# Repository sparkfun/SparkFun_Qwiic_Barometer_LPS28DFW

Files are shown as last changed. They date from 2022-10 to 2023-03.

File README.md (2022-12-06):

SparkFun Absolute Digital Barometer - LPS28DFW (Qwiic)
======================================================

<table class="table table-striped table-bordered"?
  <tr align="center">
    <td><a href="https://www.sparkfun.com/products/21221">SparkFun Absolute Digital Barometer - LPS28DFW (Qwiic)</a></td>
    <td><a href="https://www.sparkfun.com/products/21222">SparkFun Micro Triple Axis Accelerometer Breakout - BMA400 (Qwiic)</a></td>
  </tr>
  <tr align="center">
    <td><a href="https://www.sparkfun.com/products/21221"><i>SparkFun Absolute Digital Barometer - LPS28DFW (Qwiic)</i></a></td>
    <td><a href="https://www.sparkfun.com/products/21222"><i>SparkFun Micro Absolute Digital Barometer - LPS28DFW (Qwiic)</i></a></td>
  </tr>
</table>

The SparkFun Qwiic LPS28DFW Absolute Digital Barometer offers a unique barometer breakout featuring the LPS28DFW from STMicroelectronics<sup>&copy;</sup>. The LPS28DFW is an absolute barometer with a water-resistant package making it perfect for pressure measurement applications where the sensor is exposed to or even submerged in water. The Qwiic system allows for integration into your I<sup>2</sup>C system with no soldering required. This Qwiic breakout also includes 0.1"-spaced PTH pins connected to the sensor's communication interface and interrupt pins for applications that require a traditional soldered connection.

The sensor has two full-scale measurement ranges of 260 - 1260hPa and 260 - 4060hPa with an absolute pressure accuracy of 0.5hPa. The LPS28DFW is composed of a piezoresistive pressure sensor with a metal lid and gel encasing to protect the sensing elements from water and other environmental hazards.

Repository Contents
-------------------
* **/Documents** - Datasheet
* **/Hardware** - Eagle design files (.brd, .sch)
* **/Production** - Production panel files (.brd)

Documentation
-------------
* **[Hookup Guide](https://learn.sparkfun.com/tutorials/sparkfun-absolute-digital-barometer---lps28dfw-qwiic-hookup-guide)** - Basic Hookup Guide for the SparkFun Absolute Digital Barometer - LPS28DFW (Qwiic). 
* **[LPS28DFW Arduino Library](https://github.com/sparkfun/SparkFun_LPS28DFW_Arduino_Library)** - Arduino library for the LPS28DFW based off the STMicroelectronics API.

Product Versions
----------------
* [SEN-21221](https://www.sparkfun.com/products/21208) - Standard Size Initial Release.
* [SEN-21222](https://www.sparkfun.com/products/21207) - Micro Size Initial Release.

License Information
-------------------

This product is _**open source**_! 

Please review the LICENSE.md file for license information.

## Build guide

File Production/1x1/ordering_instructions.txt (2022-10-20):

panel size, 169x117mm
PCB thickness, 1.6mm
number of layers, 2
soldermask color, Red
silkscreen color, White
oz copper, 1oz
finish, HASL lead free
stencils, top
pcs per panel, 24
min trace width, 0.2540mm / 0.0100in
min drill size, 0.3048mm / 0.0120in

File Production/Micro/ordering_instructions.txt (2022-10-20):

panel size, 79x170mm
PCB thickness, 1.6mm
number of layers, 2
soldermask color, Red
silkscreen color, White
oz copper, 1oz
finish, HASL lead free
stencils, top
pcs per panel, 64
min trace width, 0.1270mm / 0.0050in
min drill size, 0.3048mm / 0.0120in

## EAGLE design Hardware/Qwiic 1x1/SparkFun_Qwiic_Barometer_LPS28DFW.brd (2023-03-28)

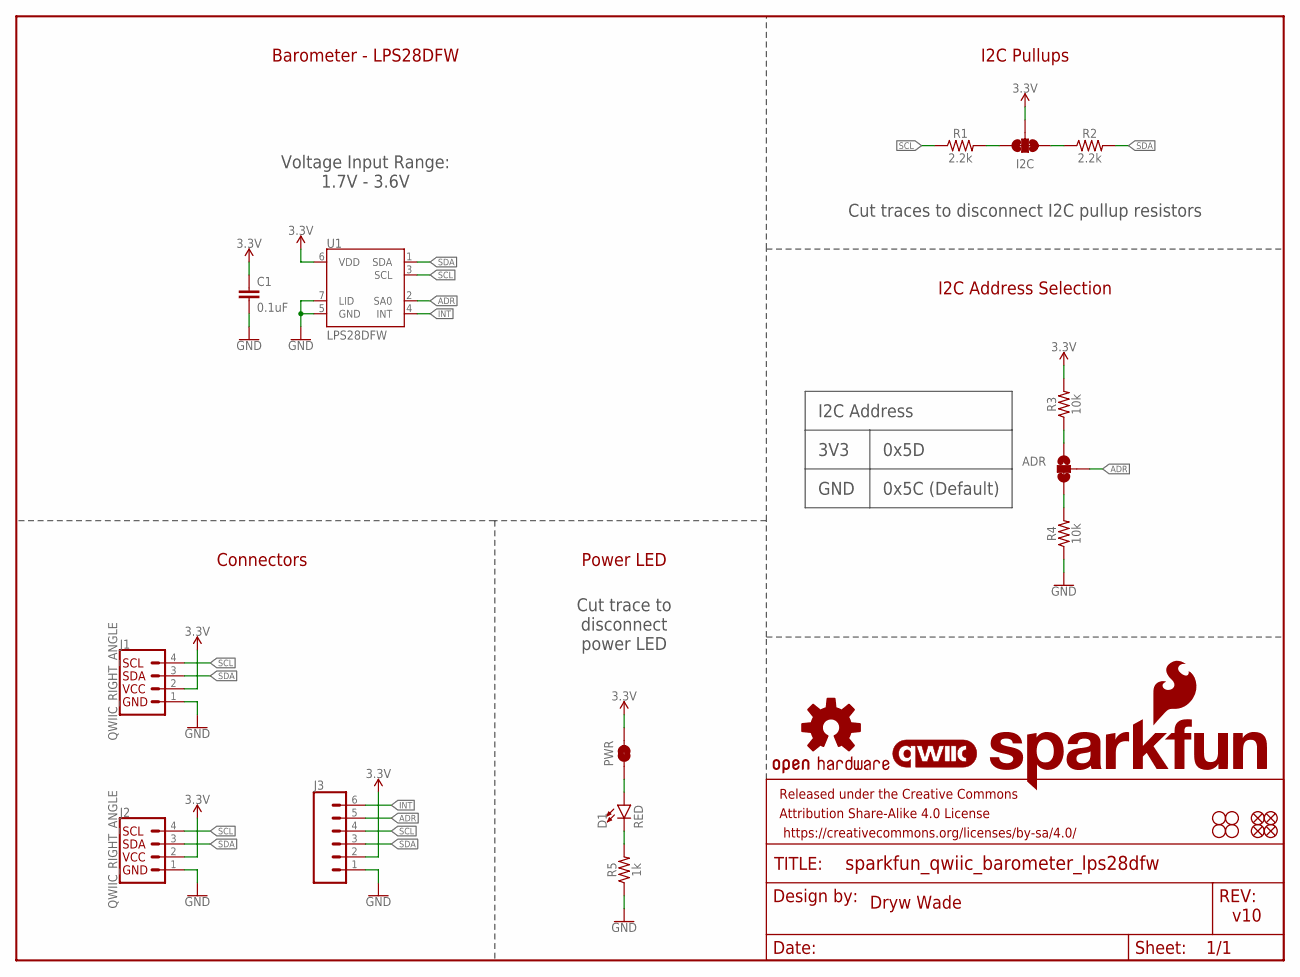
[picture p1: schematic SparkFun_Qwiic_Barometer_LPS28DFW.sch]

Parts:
ADR: JUMPER-SMT_3_1-NC_TRACE_SILK; SMT-JUMPER_3_1-NC_TRACE_SILK
C1: 0.1uF; 0603
D1: RED; LED-0603
FD1, FD2, FD3, FD4: FIDUCIAL1X2; FIDUCIAL-1X2
FRAME1: FRAME-LETTER; CREATIVE_COMMONS
H1, H2, H3, H4: STAND-OFF
I2C: JUMPER-SMT_3_2-NC_TRACE_SILK; SMT-JUMPER_3_2-NC_TRACE_SILK
J1, J2: QWIIC_RIGHT_ANGLE; JST04_1MM_RA
J3: CONN_06NO_SILK_NO_POP; 1X06_NO_SILK
LOGO1: OSHW-LOGOS; OSHW-LOGO-S
LOGO2: QWIIC_LOGO_5MM; QWIIC_5MM
LOGO3: SFE_LOGO_NAME_FLAME.1_INCH; SFE_LOGO_NAME_FLAME_.1
PWR: JUMPER-SMT_2_NC_TRACE_SILK; SMT-JUMPER_2_NC_TRACE_SILK
R1, R2: 2.2k; 0603
R3, R4: 10k; 0603
R5: 1k; 0603
U1: LPS28DFW; CCLGA-7L

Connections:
3.3V: C1.1, I2C.2, J1.2, J2.2, J3.2, PWR.2, R3.2, U1.6 (VDD)
ADR: ADR.2, J3.5, U1.2 (SA0)
GND: C1.2, J1.1, J2.1, J3.1, R4.1, R5.1, U1.5 (GND), U1.7 (LID)
INT: J3.6, U1.4 (INT)
unnamed: D1.C, R5.2
unnamed: I2C.3, R1.2
unnamed: I2C.1, R2.1
unnamed: D1.A, PWR.1
unnamed: ADR.3, R4.2
unnamed: ADR.1, R3.1
SCL: J1.4, J2.4, J3.4, R1.1, U1.3 (SCL)
SDA: J1.3, J2.3, J3.3, R2.2, U1.1 (SDA)

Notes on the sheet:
Dryw Wade
v10
Barometer - LPS28DFW
I2C Pullups
I2C Address Selection
Connectors
Power LED
Cut traces to disconnect I2C pullup resistors
I2C Address
GND
3V3
0x5D
0x5C (Default)
Cut trace to disconnect power LED
Voltage Input Range: 1.7V - 3.6V

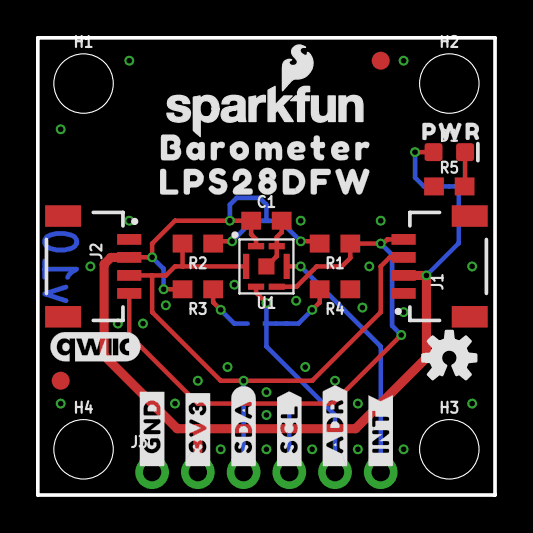
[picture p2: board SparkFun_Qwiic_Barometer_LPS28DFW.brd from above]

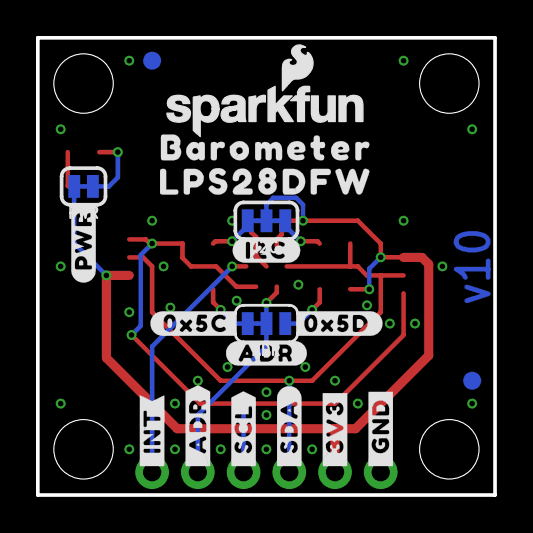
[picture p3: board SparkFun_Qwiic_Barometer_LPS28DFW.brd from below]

Board: 2 copper layers, 25.4 x 25.4 mm, 50 parts (19 on the bottom side), 12 nets.

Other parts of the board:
LOGO4: SFE_LOGO_NAME_FLAME.1_INCH; SFE_LOGO_NAME_FLAME_.1
U$1, U$2: #_GND#0
U$3, U$4: #_3V3#0
U$5, U$6: #_SDA#0
U$7, U$8: #_SCL#0
U$9: #I2C#0
U$10: #ADR#0
U$11, U$14: BAROMETER0
U$12, U$15: LPS28DFW0
U$13: #PWR#0
U$16: #0X5D#0
U$17: #0X5C#0
U$18: PWR0
U$19: ORDERING_INSTRUCTIONS
U$20, U$21: #_INT#0
U$22, U$23: #_ADR#0

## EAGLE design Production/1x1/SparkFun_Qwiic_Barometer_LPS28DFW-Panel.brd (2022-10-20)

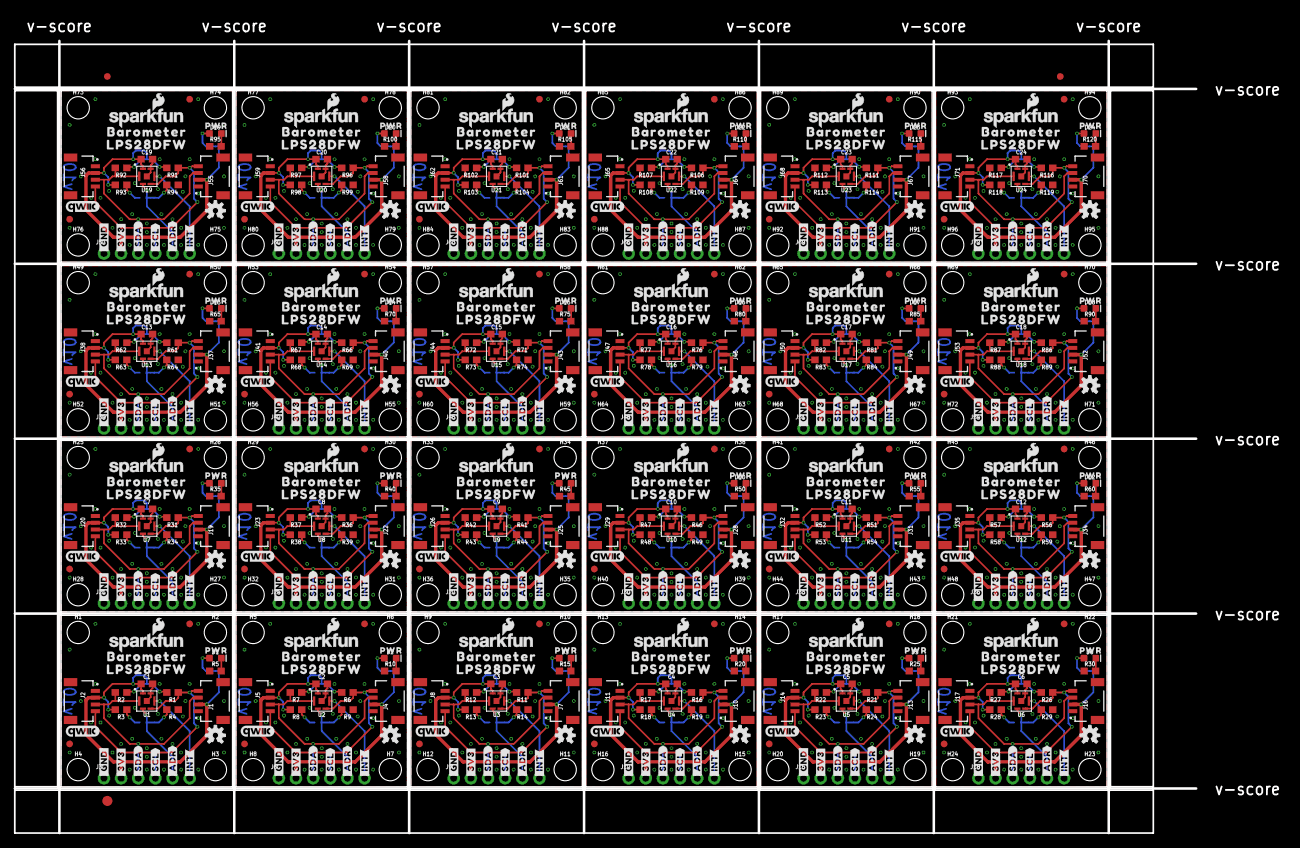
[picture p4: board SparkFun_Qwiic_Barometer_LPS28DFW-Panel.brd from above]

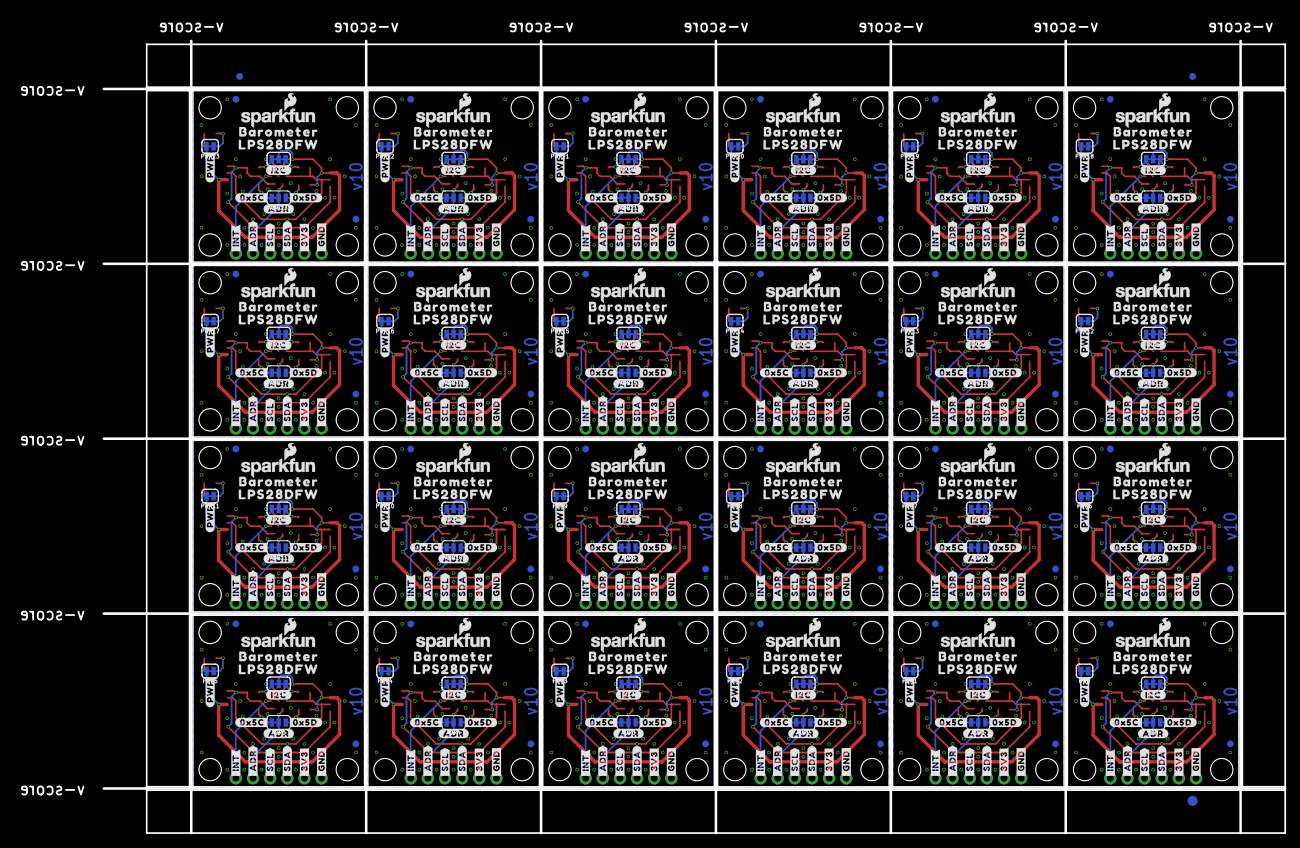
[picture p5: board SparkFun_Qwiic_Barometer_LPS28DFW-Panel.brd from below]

Board: 2 copper layers, 175.0 x 117.3 mm, 1158 parts (459 on the bottom side), 288 nets.

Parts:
ADR, ADR1, ADR2, ADR3, ADR4, ADR5, ADR6, ADR7, ADR8, ADR9, ADR10, ADR11, ADR12, ADR13, ADR14, ADR15, ADR16, ADR17, ADR18, ADR19, ADR20, ADR21, ADR22, ADR23: JUMPER-SMT_3_1-NC_TRACE_SILK; SMT-JUMPER_3_1-NC_TRACE_SILK
C1, C2, C3, C4, C5, C6, C7, C8, C9, C10, C11, C12, C13, C14, C15, C16, C17, C18, C19, C20, C21, C22, C23, C24: 0.1uF; 0603
D1, D2, D3, D4, D5, D6, D7, D8, D9, D10, D11, D12, D13, D14, D15, D16, D17, D18, D19, D20, D21, D22, D23, D24: RED; LED-0603
E$1, E$2, E$3, E$4: FIDUCIAL-1X2
E$5, E$6: FIDUCIAL-1.5X3
FD1, FD2, FD3, FD4, FD5, FD6, FD7, FD8, FD9, FD10, FD11, FD12, FD13, FD14, FD15, FD16, FD17, FD18, FD19, FD20, FD21, FD22, FD23, FD24, FD25, FD26, FD27, FD28, FD29, FD30, FD31, FD32, FD33, FD34, FD35, FD36, FD37, FD38, FD39, FD40, FD41, FD42, FD43, FD44, FD45, FD46, FD47, FD48, FD49, FD50, FD51, FD52, FD53, FD54, FD55, FD56, FD57, FD58, FD59, FD60, FD61, FD62, FD63, FD64, FD65, FD66, FD67, FD68, FD69, FD70, FD71, FD72, FD73, FD74, FD75, FD76, FD77, FD78, FD79, FD80, FD81, FD82, FD83, FD84, FD85, FD86, FD87, FD88, FD89, FD90, FD91, FD92, FD93, FD94, FD95, FD96: FIDUCIAL1X2; FIDUCIAL-1X2
H1, H2, H3, H4, H5, H6, H7, H8, H9, H10, H11, H12, H13, H14, H15, H16, H17, H18, H19, H20, H21, H22, H23, H24, H25, H26, H27, H28, H29, H30, H31, H32, H33, H34, H35, H36, H37, H38, H39, H40, H41, H42, H43, H44, H45, H46, H47, H48, H49, H50, H51, H52, H53, H54, H55, H56, H57, H58, H59, H60, H61, H62, H63, H64, H65, H66, H67, H68, H69, H70, H71, H72, H73, H74, H75, H76, H77, H78, H79, H80, H81, H82, H83, H84, H85, H86, H87, H88, H89, H90, H91, H92, H93, H94, H95, H96: STAND-OFF
I2C, I2C1, I2C2, I2C3, I2C4, I2C5, I2C6, I2C7, I2C8, I2C9, I2C10, I2C11, I2C12, I2C13, I2C14, I2C15, I2C16, I2C17, I2C18, I2C19, I2C20, I2C21, I2C22, I2C23: JUMPER-SMT_3_2-NC_TRACE_SILK; SMT-JUMPER_3_2-NC_TRACE_SILK
J1, J2, J4, J5, J7, J8, J10, J11, J13, J14, J16, J17, J19, J20, J22, J23, J25, J26, J28, J29, J31, J32, J34, J35, J37, J38, J40, J41, J43, J44, J46, J47, J49, J50, J52, J53, J55, J56, J58, J59, J61, J62, J64, J65, J67, J68, J70, J71: QWIIC_RIGHT_ANGLE; JST04_1MM_RA
J3, J6, J9, J12, J15, J18, J21, J24, J27, J30, J33, J36, J39, J42, J45, J48, J51, J54, J57, J60, J63, J66, J69, J72: 1X06_NO_SILK
LOGO1, LOGO5, LOGO9, LOGO13, LOGO17, LOGO21, LOGO25, LOGO29, LOGO33, LOGO37, LOGO41, LOGO45, LOGO49, LOGO53, LOGO57, LOGO61, LOGO65, LOGO69, LOGO73, LOGO77, LOGO81, LOGO85, LOGO89, LOGO93: OSHW-LOGOS; OSHW-LOGO-S
LOGO2, LOGO6, LOGO10, LOGO14, LOGO18, LOGO22, LOGO26, LOGO30, LOGO34, LOGO38, LOGO42, LOGO46, LOGO50, LOGO54, LOGO58, LOGO62, LOGO66, LOGO70, LOGO74, LOGO78, LOGO82, LOGO86, LOGO90, LOGO94: QWIIC_LOGO_5MM; QWIIC_5MM
LOGO3, LOGO4, LOGO7, LOGO8, LOGO11, LOGO12, LOGO15, LOGO16, LOGO19, LOGO20, LOGO23, LOGO24, LOGO27, LOGO28, LOGO31, LOGO32, LOGO35, LOGO36, LOGO39, LOGO40, LOGO43, LOGO44, LOGO47, LOGO48, LOGO51, LOGO52, LOGO55, LOGO56, LOGO59, LOGO60, LOGO63, LOGO64, LOGO67, LOGO68, LOGO71, LOGO72, LOGO75, LOGO76, LOGO79, LOGO80, LOGO83, LOGO84, LOGO87, LOGO88, LOGO91, LOGO92, LOGO95, LOGO96: SFE_LOGO_NAME_FLAME.1_INCH; SFE_LOGO_NAME_FLAME_.1
PWR, PWR1, PWR2, PWR3, PWR4, PWR5, PWR6, PWR7, PWR8, PWR9, PWR10, PWR11, PWR12, PWR13, PWR14, PWR15, PWR16, PWR17, PWR18, PWR19, PWR20, PWR21, PWR22, PWR23: JUMPER-SMT_2_NC_TRACE_SILK; SMT-JUMPER_2_NC_TRACE_SILK
R1, R2, R6, R7, R11, R12, R16, R17, R21, R22, R26, R27, R31, R32, R36, R37, R41, R42, R46, R47, R51, R52, R56, R57, R61, R62, R66, R67, R71, R72, R76, R77, R81, R82, R86, R87, R91, R92, R96, R97, R101, R102, R106, R107, R111, R112, R116, R117: 2.2k; 0603
R3, R4, R8, R9, R13, R14, R18, R19, R23, R24, R28, R29, R33, R34, R38, R39, R43, R44, R48, R49, R53, R54, R58, R59, R63, R64, R68, R69, R73, R74, R78, R79, R83, R84, R88, R89, R93, R94, R98, R99, R103, R104, R108, R109, R113, R114, R118, R119: 10k; 0603
R5, R10, R15, R20, R25, R30, R35, R40, R45, R50, R55, R60, R65, R70, R75, R80, R85, R90, R95, R100, R105, R110, R115, R120: 1k; 0603
U1, U2, U3, U4, U5, U6, U7, U8, U9, U10, U11, U12, U13, U14, U15, U16, U17, U18, U19, U20, U21, U22, U23, U24: LPS28DFW
U$1, U$2, U$19, U$24, U$45, U$46, U$67, U$68, U$89, U$90, U$111, U$112, U$133, U$134, U$155, U$156, U$177, U$178, U$199, U$200, U$221, U$222, U$243, U$244, U$265, U$266, U$287, U$288, U$309, U$310, U$331, U$332, U$353, U$354, U$375, U$376, U$397, U$398, U$419, U$420, U$441, U$442, U$463, U$464, U$485, U$486, U$507, U$508: #_GND#0
U$3, U$4, U$25, U$26, U$47, U$48, U$69, U$70, U$91, U$92, U$113, U$114, U$135, U$136, U$157, U$158, U$179, U$180, U$201, U$202, U$223, U$224, U$245, U$246, U$267, U$268, U$289, U$290, U$311, U$312, U$333, U$334, U$355, U$356, U$377, U$378, U$399, U$400, U$421, U$422, U$443, U$444, U$465, U$466, U$487, U$488, U$509, U$510: #_3V3#0
U$5, U$6, U$27, U$28, U$49, U$50, U$71, U$72, U$93, U$94, U$115, U$116, U$137, U$138, U$159, U$160, U$181, U$182, U$203, U$204, U$225, U$226, U$247, U$248, U$269, U$270, U$291, U$292, U$313, U$314, U$335, U$336, U$357, U$358, U$379, U$380, U$401, U$402, U$423, U$424, U$445, U$446, U$467, U$468, U$489, U$490, U$511, U$512: #_SDA#0
U$7, U$8, U$29, U$30, U$51, U$52, U$73, U$74, U$95, U$96, U$117, U$118, U$139, U$140, U$161, U$162, U$183, U$184, U$205, U$206, U$227, U$228, U$249, U$250, U$271, U$272, U$293, U$294, U$315, U$316, U$337, U$338, U$359, U$360, U$381, U$382, U$403, U$404, U$425, U$426, U$447, U$448, U$469, U$470, U$491, U$492, U$513, U$514: #_SCL#0
U$9, U$31, U$53, U$75, U$97, U$119, U$141, U$163, U$185, U$207, U$229, U$251, U$273, U$295, U$317, U$339, U$361, U$383, U$405, U$427, U$449, U$471, U$493, U$515: #I2C#0
U$10, U$32, U$54, U$76, U$98, U$120, U$142, U$164, U$186, U$208, U$230, U$252, U$274, U$296, U$318, U$340, U$362, U$384, U$406, U$428, U$450, U$472, U$494, U$516: #ADR#0
U$11, U$14, U$33, U$36, U$55, U$58, U$77, U$80, U$99, U$102, U$121, U$124, U$143, U$146, U$165, U$168, U$187, U$190, U$209, U$212, U$231, U$234, U$253, U$256, U$275, U$278, U$297, U$300, U$319, U$322, U$341, U$344, U$363, U$366, U$385, U$388, U$407, U$410, U$429, U$432, U$451, U$454, U$473, U$476, U$495, U$498, U$517, U$520: BAROMETER0
U$12, U$15, U$34, U$37, U$56, U$59, U$78, U$81, U$100, U$103, U$122, U$125, U$144, U$147, U$166, U$169, U$188, U$191, U$210, U$213, U$232, U$235, U$254, U$257, U$276, U$279, U$298, U$301, U$320, U$323, U$342, U$345, U$364, U$367, U$386, U$389, U$408, U$411, U$430, U$433, U$452, U$455, U$474, U$477, U$496, U$499, U$518, U$521: LPS28DFW0
U$13, U$35, U$57, U$79, U$101, U$123, U$145, U$167, U$189, U$211, U$233, U$255, U$277, U$299, U$321, U$343, U$365, U$387, U$409, U$431, U$453, U$475, U$497, U$519: #PWR#0
U$16, U$38, U$60, U$82, U$104, U$126, U$148, U$170, U$192, U$214, U$236, U$258, U$280, U$302, U$324, U$346, U$368, U$390, U$412, U$434, U$456, U$478, U$500, U$522: #0X5D#0
U$17, U$39, U$61, U$83, U$105, U$127, U$149, U$171, U$193, U$215, U$237, U$259, U$281, U$303, U$325, U$347, U$369, U$391, U$413, U$435, U$457, U$479, U$501, U$523: #0X5C#0
U$18, U$44, U$66, U$88, U$110, U$132, U$154, U$176, U$198, U$220, U$242, U$264, U$286, U$308, U$330, U$352, U$374, U$396, U$418, U$440, U$462, U$484, U$506, U$528: PWR0
U$20, U$21, U$40, U$41, U$62, U$63, U$84, U$85, U$106, U$107, U$128, U$129, U$150, U$151, U$172, U$173, U$194, U$195, U$216, U$217, U$238, U$239, U$260, U$261, U$282, U$283, U$304, U$305, U$326, U$327, U$348, U$349, U$370, U$371, U$392, U$393, U$414, U$415, U$436, U$437, U$458, U$459, U$480, U$481, U$502, U$503, U$524, U$525: #_INT#0
U$22, U$23, U$42, U$43, U$64, U$65, U$86, U$87, U$108, U$109, U$130, U$131, U$152, U$153, U$174, U$175, U$196, U$197, U$218, U$219, U$240, U$241, U$262, U$263, U$284, U$285, U$306, U$307, U$328, U$329, U$350, U$351, U$372, U$373, U$394, U$395, U$416, U$417, U$438, U$439, U$460, U$461, U$482, U$483, U$504, U$505, U$526, U$527: #_ADR#0

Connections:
3.3V: C1.1, I2C.2, J1.2, J2.2, J3.2, PWR.2, R3.2, U1.6
3.3V1: C2.1, I2C1.2, J4.2, J5.2, J6.2, PWR1.2, R8.2, U2.6
3.3V2: C3.1, I2C2.2, J7.2, J8.2, J9.2, PWR2.2, R13.2, U3.6
3.3V3: C4.1, I2C3.2, J10.2, J11.2, J12.2, PWR3.2, R18.2, U4.6
3.3V4: C5.1, I2C4.2, J13.2, J14.2, J15.2, PWR4.2, R23.2, U5.6
3.3V5: C6.1, I2C5.2, J16.2, J17.2, J18.2, PWR5.2, R28.2, U6.6
3.3V6: C7.1, I2C6.2, J19.2, J20.2, J21.2, PWR6.2, R33.2, U7.6
3.3V7: C8.1, I2C7.2, J22.2, J23.2, J24.2, PWR7.2, R38.2, U8.6
3.3V8: C9.1, I2C8.2, J25.2, J26.2, J27.2, PWR8.2, R43.2, U9.6
3.3V9: C10.1, I2C9.2, J28.2, J29.2, J30.2, PWR9.2, R48.2, U10.6
3.3V10: C11.1, I2C10.2, J31.2, J32.2, J33.2, PWR10.2, R53.2, U11.6
3.3V11: C12.1, I2C11.2, J34.2, J35.2, J36.2, PWR11.2, R58.2, U12.6
3.3V12: C13.1, I2C12.2, J37.2, J38.2, J39.2, PWR12.2, R63.2, U13.6
3.3V13: C14.1, I2C13.2, J40.2, J41.2, J42.2, PWR13.2, R68.2, U14.6
3.3V14: C15.1, I2C14.2, J43.2, J44.2, J45.2, PWR14.2, R73.2, U15.6
3.3V15: C16.1, I2C15.2, J46.2, J47.2, J48.2, PWR15.2, R78.2, U16.6
3.3V16: C17.1, I2C16.2, J49.2, J50.2, J51.2, PWR16.2, R83.2, U17.6
3.3V17: C18.1, I2C17.2, J52.2, J53.2, J54.2, PWR17.2, R88.2, U18.6
3.3V18: C19.1, I2C18.2, J55.2, J56.2, J57.2, PWR18.2, R93.2, U19.6
3.3V19: C20.1, I2C19.2, J58.2, J59.2, J60.2, PWR19.2, R98.2, U20.6
3.3V20: C21.1, I2C20.2, J61.2, J62.2, J63.2, PWR20.2, R103.2, U21.6
3.3V21: C22.1, I2C21.2, J64.2, J65.2, J66.2, PWR21.2, R108.2, U22.6
3.3V22: C23.1, I2C22.2, J67.2, J68.2, J69.2, PWR22.2, R113.2, U23.6
3.3V23: C24.1, I2C23.2, J70.2, J71.2, J72.2, PWR23.2, R118.2, U24.6
ADR: ADR.2, J3.5, U1.2
ADR1: ADR1.2, J6.5, U2.2
ADR2: ADR2.2, J9.5, U3.2
ADR3: ADR3.2, J12.5, U4.2
ADR4: ADR4.2, J15.5, U5.2
ADR5: ADR5.2, J18.5, U6.2
ADR6: ADR6.2, J21.5, U7.2
ADR7: ADR7.2, J24.5, U8.2
ADR8: ADR8.2, J27.5, U9.2
ADR9: ADR9.2, J30.5, U10.2
ADR10: ADR10.2, J33.5, U11.2
ADR11: ADR11.2, J36.5, U12.2
ADR12: ADR12.2, J39.5, U13.2
ADR13: ADR13.2, J42.5, U14.2
ADR14: ADR14.2, J45.5, U15.2
ADR15: ADR15.2, J48.5, U16.2
ADR16: ADR16.2, J51.5, U17.2
ADR17: ADR17.2, J54.5, U18.2
ADR18: ADR18.2, J57.5, U19.2
ADR19: ADR19.2, J60.5, U20.2
ADR20: ADR20.2, J63.5, U21.2
ADR21: ADR21.2, J66.5, U22.2
ADR22: ADR22.2, J69.5, U23.2
ADR23: ADR23.2, J72.5, U24.2
GND: C1.2, J1.1, J2.1, J3.1, R4.1, R5.1, U1.5, U1.7
GND1: C2.2, J4.1, J5.1, J6.1, R9.1, R10.1, U2.5, U2.7
GND2: C3.2, J7.1, J8.1, J9.1, R14.1, R15.1, U3.5, U3.7
GND3: C4.2, J10.1, J11.1, J12.1, R19.1, R20.1, U4.5, U4.7
GND4: C5.2, J13.1, J14.1, J15.1, R24.1, R25.1, U5.5, U5.7
GND5: C6.2, J16.1, J17.1, J18.1, R29.1, R30.1, U6.5, U6.7
GND6: C7.2, J19.1, J20.1, J21.1, R34.1, R35.1, U7.5, U7.7
GND7: C8.2, J22.1, J23.1, J24.1, R39.1, R40.1, U8.5, U8.7
GND8: C9.2, J25.1, J26.1, J27.1, R44.1, R45.1, U9.5, U9.7
GND9: C10.2, J28.1, J29.1, J30.1, R49.1, R50.1, U10.5, U10.7
GND10: C11.2, J31.1, J32.1, J33.1, R54.1, R55.1, U11.5, U11.7
GND11: C12.2, J34.1, J35.1, J36.1, R59.1, R60.1, U12.5, U12.7
GND12: C13.2, J37.1, J38.1, J39.1, R64.1, R65.1, U13.5, U13.7
GND13: C14.2, J40.1, J41.1, J42.1, R69.1, R70.1, U14.5, U14.7
GND14: C15.2, J43.1, J44.1, J45.1, R74.1, R75.1, U15.5, U15.7
GND15: C16.2, J46.1, J47.1, J48.1, R79.1, R80.1, U16.5, U16.7
GND16: C17.2, J49.1, J50.1, J51.1, R84.1, R85.1, U17.5, U17.7
GND17: C18.2, J52.1, J53.1, J54.1, R89.1, R90.1, U18.5, U18.7
GND18: C19.2, J55.1, J56.1, J57.1, R94.1, R95.1, U19.5, U19.7
GND19: C20.2, J58.1, J59.1, J60.1, R99.1, R100.1, U20.5, U20.7
GND20: C21.2, J61.1, J62.1, J63.1, R104.1, R105.1, U21.5, U21.7
GND21: C22.2, J64.1, J65.1, J66.1, R109.1, R110.1, U22.5, U22.7
GND22: C23.2, J67.1, J68.1, J69.1, R114.1, R115.1, U23.5, U23.7
GND23: C24.2, J70.1, J71.1, J72.1, R119.1, R120.1, U24.5, U24.7
INT: J3.6, U1.4
INT1: J6.6, U2.4
INT2: J9.6, U3.4
INT3: J12.6, U4.4
INT4: J15.6, U5.4
INT5: J18.6, U6.4
INT6: J21.6, U7.4
INT7: J24.6, U8.4
INT8: J27.6, U9.4
INT9: J30.6, U10.4
INT10: J33.6, U11.4
INT11: J36.6, U12.4
INT12: J39.6, U13.4
INT13: J42.6, U14.4
INT14: J45.6, U15.4
INT15: J48.6, U16.4
INT16: J51.6, U17.4
INT17: J54.6, U18.4
INT18: J57.6, U19.4
INT19: J60.6, U20.4
INT20: J63.6, U21.4
INT21: J66.6, U22.4
INT22: J69.6, U23.4
INT23: J72.6, U24.4
unnamed: D1.C, R5.2
unnamed: I2C.3, R1.2
unnamed: I2C.1, R2.1
unnamed: D1.A, PWR.1
unnamed: ADR.3, R4.2
unnamed: ADR.1, R3.1
unnamed: I2C1.3, R6.2
unnamed: I2C1.1, R7.1
unnamed: ADR1.3, R9.2
unnamed: ADR1.1, R8.1
unnamed: D2.C, R10.2
unnamed: D2.A, PWR1.1
unnamed: I2C2.3, R11.2
unnamed: I2C2.1, R12.1
unnamed: ADR2.3, R14.2
unnamed: ADR2.1, R13.1
unnamed: D3.C, R15.2
unnamed: D3.A, PWR2.1
unnamed: I2C3.3, R16.2
unnamed: I2C3.1, R17.1
unnamed: ADR3.3, R19.2
unnamed: ADR3.1, R18.1
unnamed: D4.C, R20.2
unnamed: D4.A, PWR3.1
unnamed: I2C4.3, R21.2
unnamed: I2C4.1, R22.1
unnamed: ADR4.3, R24.2
unnamed: ADR4.1, R23.1
unnamed: D5.C, R25.2
unnamed: D5.A, PWR4.1
unnamed: I2C5.3, R26.2
unnamed: I2C5.1, R27.1
unnamed: ADR5.3, R29.2
unnamed: ADR5.1, R28.1
unnamed: D6.C, R30.2
unnamed: D6.A, PWR5.1
unnamed: I2C6.3, R31.2
unnamed: I2C6.1, R32.1
unnamed: ADR6.3, R34.2
unnamed: ADR6.1, R33.1
unnamed: D7.C, R35.2
unnamed: D7.A, PWR6.1
unnamed: I2C7.3, R36.2
unnamed: I2C7.1, R37.1
unnamed: ADR7.3, R39.2
unnamed: ADR7.1, R38.1
unnamed: D8.C, R40.2
unnamed: D8.A, PWR7.1
unnamed: I2C8.3, R41.2
unnamed: I2C8.1, R42.1
unnamed: ADR8.3, R44.2
unnamed: ADR8.1, R43.1
unnamed: D9.C, R45.2
unnamed: D9.A, PWR8.1
unnamed: I2C9.3, R46.2
unnamed: I2C9.1, R47.1
unnamed: ADR9.3, R49.2
unnamed: ADR9.1, R48.1
unnamed: D10.C, R50.2
unnamed: D10.A, PWR9.1
unnamed: I2C10.3, R51.2
unnamed: I2C10.1, R52.1
unnamed: ADR10.3, R54.2
unnamed: ADR10.1, R53.1
unnamed: D11.C, R55.2
unnamed: D11.A, PWR10.1
unnamed: I2C11.3, R56.2
unnamed: I2C11.1, R57.1
unnamed: ADR11.3, R59.2
unnamed: ADR11.1, R58.1
unnamed: D12.C, R60.2
unnamed: D12.A, PWR11.1
unnamed: I2C12.3, R61.2
unnamed: I2C12.1, R62.1
unnamed: ADR12.3, R64.2
unnamed: ADR12.1, R63.1
unnamed: D13.C, R65.2
unnamed: D13.A, PWR12.1
unnamed: I2C13.3, R66.2
unnamed: I2C13.1, R67.1
unnamed: ADR13.3, R69.2
unnamed: ADR13.1, R68.1
unnamed: D14.C, R70.2
unnamed: D14.A, PWR13.1
unnamed: I2C14.3, R71.2
unnamed: I2C14.1, R72.1
unnamed: ADR14.3, R74.2
unnamed: ADR14.1, R73.1
unnamed: D15.C, R75.2
unnamed: D15.A, PWR14.1
unnamed: I2C15.3, R76.2
unnamed: I2C15.1, R77.1
unnamed: ADR15.3, R79.2
unnamed: ADR15.1, R78.1
unnamed: D16.C, R80.2
unnamed: D16.A, PWR15.1
unnamed: I2C16.3, R81.2
unnamed: I2C16.1, R82.1
unnamed: ADR16.3, R84.2
unnamed: ADR16.1, R83.1
unnamed: D17.C, R85.2
unnamed: D17.A, PWR16.1
unnamed: I2C17.3, R86.2
unnamed: I2C17.1, R87.1
unnamed: ADR17.3, R89.2
unnamed: ADR17.1, R88.1
unnamed: D18.C, R90.2
unnamed: D18.A, PWR17.1
unnamed: I2C18.3, R91.2
unnamed: I2C18.1, R92.1
unnamed: ADR18.3, R94.2
unnamed: ADR18.1, R93.1
unnamed: D19.C, R95.2
unnamed: D19.A, PWR18.1
unnamed: I2C19.3, R96.2
unnamed: I2C19.1, R97.1
unnamed: ADR19.3, R99.2
unnamed: ADR19.1, R98.1
unnamed: D20.C, R100.2
unnamed: D20.A, PWR19.1
unnamed: I2C20.3, R101.2
unnamed: I2C20.1, R102.1
unnamed: ADR20.3, R104.2
unnamed: ADR20.1, R103.1
unnamed: D21.C, R105.2
unnamed: D21.A, PWR20.1
unnamed: I2C21.3, R106.2
unnamed: I2C21.1, R107.1
unnamed: ADR21.3, R109.2
unnamed: ADR21.1, R108.1
unnamed: D22.C, R110.2
unnamed: D22.A, PWR21.1
unnamed: I2C22.3, R111.2
unnamed: I2C22.1, R112.1
unnamed: ADR22.3, R114.2
unnamed: ADR22.1, R113.1
unnamed: D23.C, R115.2
unnamed: D23.A, PWR22.1
unnamed: I2C23.3, R116.2
unnamed: I2C23.1, R117.1
unnamed: ADR23.3, R119.2
unnamed: ADR23.1, R118.1
unnamed: D24.C, R120.2
unnamed: D24.A, PWR23.1
SCL: J1.4, J2.4, J3.4, R1.1, U1.3
SCL1: J4.4, J5.4, J6.4, R6.1, U2.3
SCL2: J7.4, J8.4, J9.4, R11.1, U3.3
SCL3: J10.4, J11.4, J12.4, R16.1, U4.3
SCL4: J13.4, J14.4, J15.4, R21.1, U5.3
SCL5: J16.4, J17.4, J18.4, R26.1, U6.3
SCL6: J19.4, J20.4, J21.4, R31.1, U7.3
SCL7: J22.4, J23.4, J24.4, R36.1, U8.3
SCL8: J25.4, J26.4, J27.4, R41.1, U9.3
SCL9: J28.4, J29.4, J30.4, R46.1, U10.3
SCL10: J31.4, J32.4, J33.4, R51.1, U11.3
SCL11: J34.4, J35.4, J36.4, R56.1, U12.3
SCL12: J37.4, J38.4, J39.4, R61.1, U13.3
SCL13: J40.4, J41.4, J42.4, R66.1, U14.3
SCL14: J43.4, J44.4, J45.4, R71.1, U15.3
SCL15: J46.4, J47.4, J48.4, R76.1, U16.3
SCL16: J49.4, J50.4, J51.4, R81.1, U17.3
SCL17: J52.4, J53.4, J54.4, R86.1, U18.3
SCL18: J55.4, J56.4, J57.4, R91.1, U19.3
SCL19: J58.4, J59.4, J60.4, R96.1, U20.3
SCL20: J61.4, J62.4, J63.4, R101.1, U21.3
SCL21: J64.4, J65.4, J66.4, R106.1, U22.3
SCL22: J67.4, J68.4, J69.4, R111.1, U23.3
SCL23: J70.4, J71.4, J72.4, R116.1, U24.3
SDA: J1.3, J2.3, J3.3, R2.2, U1.1
SDA1: J4.3, J5.3, J6.3, R7.2, U2.1
SDA2: J7.3, J8.3, J9.3, R12.2, U3.1
SDA3: J10.3, J11.3, J12.3, R17.2, U4.1
SDA4: J13.3, J14.3, J15.3, R22.2, U5.1
SDA5: J16.3, J17.3, J18.3, R27.2, U6.1
SDA6: J19.3, J20.3, J21.3, R32.2, U7.1
SDA7: J22.3, J23.3, J24.3, R37.2, U8.1
SDA8: J25.3, J26.3, J27.3, R42.2, U9.1
SDA9: J28.3, J29.3, J30.3, R47.2, U10.1
SDA10: J31.3, J32.3, J33.3, R52.2, U11.1
SDA11: J34.3, J35.3, J36.3, R57.2, U12.1
SDA12: J37.3, J38.3, J39.3, R62.2, U13.1
SDA13: J40.3, J41.3, J42.3, R67.2, U14.1
SDA14: J43.3, J44.3, J45.3, R72.2, U15.1
SDA15: J46.3, J47.3, J48.3, R77.2, U16.1
SDA16: J49.3, J50.3, J51.3, R82.2, U17.1
SDA17: J52.3, J53.3, J54.3, R87.2, U18.1
SDA18: J55.3, J56.3, J57.3, R92.2, U19.1
SDA19: J58.3, J59.3, J60.3, R97.2, U20.1
SDA20: J61.3, J62.3, J63.3, R102.2, U21.1
SDA21: J64.3, J65.3, J66.3, R107.2, U22.1
SDA22: J67.3, J68.3, J69.3, R112.2, U23.1
SDA23: J70.3, J71.3, J72.3, R117.2, U24.1

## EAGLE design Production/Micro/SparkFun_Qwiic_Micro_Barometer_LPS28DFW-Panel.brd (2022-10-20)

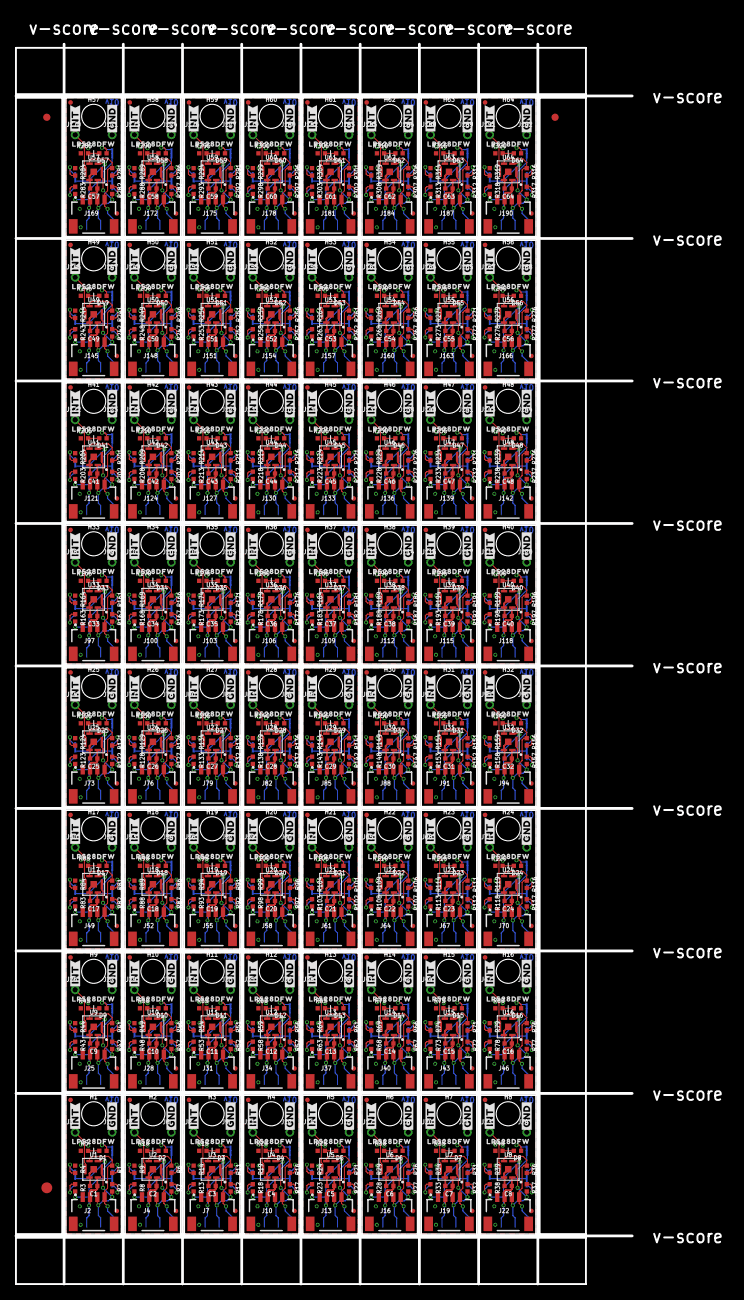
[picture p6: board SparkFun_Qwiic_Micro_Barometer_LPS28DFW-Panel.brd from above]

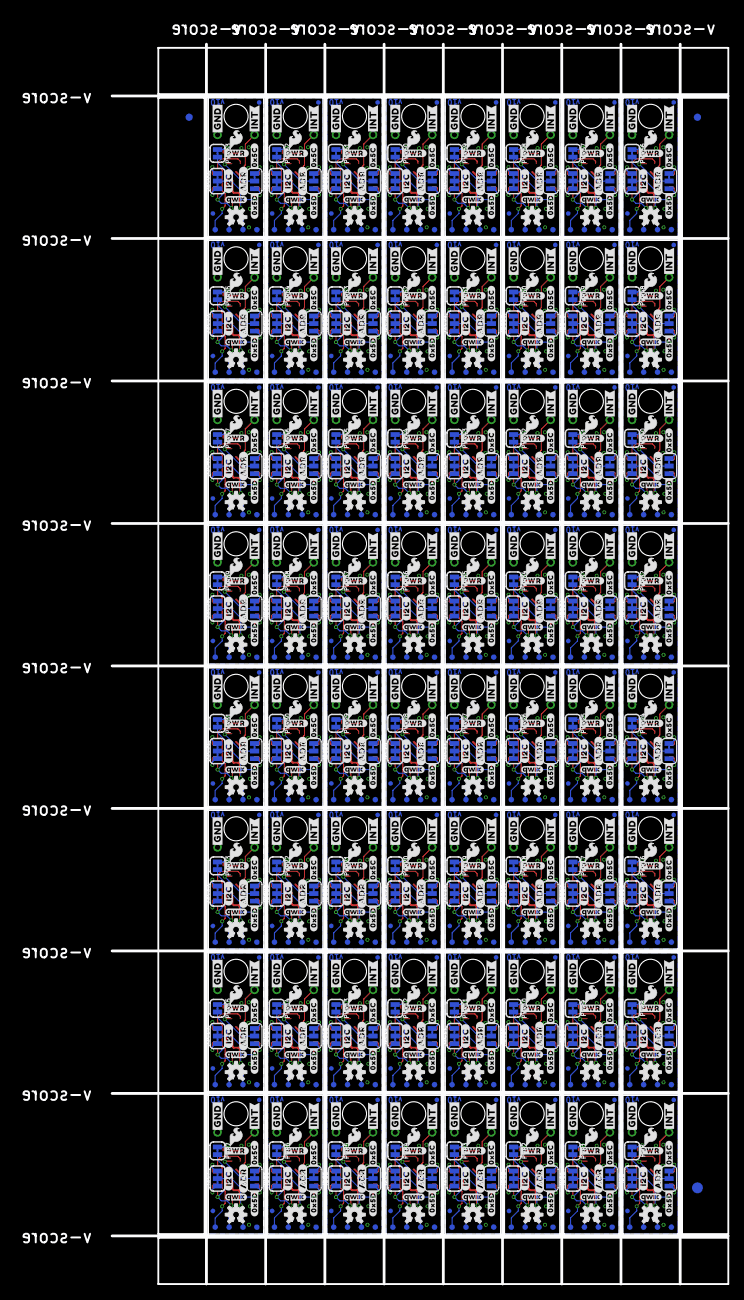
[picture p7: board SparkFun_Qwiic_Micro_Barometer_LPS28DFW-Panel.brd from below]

Board: 2 copper layers, 84.6 x 170.2 mm, 2438 parts (1219 on the bottom side), 768 nets.

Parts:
ADR, ADR1, ADR2, ADR3, ADR4, ADR5, ADR6, ADR7, ADR8, ADR9, ADR10, ADR11, ADR12, ADR13, ADR14, ADR15, ADR16, ADR17, ADR18, ADR19, ADR20, ADR21, ADR22, ADR23, ADR24, ADR25, ADR26, ADR27, ADR28, ADR29, ADR30, ADR31, ADR32, ADR33, ADR34, ADR35, ADR36, ADR37, ADR38, ADR39, ADR40, ADR41, ADR42, ADR43, ADR44, ADR45, ADR46, ADR47, ADR48, ADR49, ADR50, ADR51, ADR52, ADR53, ADR54, ADR55, ADR56, ADR57, ADR58, ADR59, ADR60, ADR61, ADR62, ADR63: JUMPER-SMT_3_1-NC_TRACE_SILK; SMT-JUMPER_3_1-NC_TRACE_SILK
C1, C2, C3, C4, C5, C6, C7, C8, C9, C10, C11, C12, C13, C14, C15, C16, C17, C18, C19, C20, C21, C22, C23, C24, C25, C26, C27, C28, C29, C30, C31, C32, C33, C34, C35, C36, C37, C38, C39, C40, C41, C42, C43, C44, C45, C46, C47, C48, C49, C50, C51, C52, C53, C54, C55, C56, C57, C58, C59, C60, C61, C62, C63, C64: 0.1uF; 0402-TIGHT
D1, D2, D3, D4, D5, D6, D7, D8, D9, D10, D11, D12, D13, D14, D15, D16, D17, D18, D19, D20, D21, D22, D23, D24, D25, D26, D27, D28, D29, D30, D31, D32, D33, D34, D35, D36, D37, D38, D39, D40, D41, D42, D43, D44, D45, D46, D47, D48, D49, D50, D51, D52, D53, D54, D55, D56, D57, D58, D59, D60, D61, D62, D63, D64: RED; LED-0402
E$1, E$2, E$3, E$4: FIDUCIAL-1X2
E$5, E$6: FIDUCIAL-1.5X3
FD1, FD2, FD3, FD4, FD5, FD6, FD7, FD8, FD9, FD10, FD11, FD12, FD13, FD14, FD15, FD16, FD17, FD18, FD19, FD20, FD21, FD22, FD23, FD24, FD25, FD26, FD27, FD28, FD29, FD30, FD31, FD32, FD33, FD34, FD35, FD36, FD37, FD38, FD39, FD40, FD41, FD42, FD43, FD44, FD45, FD46, FD47, FD48, FD49, FD50, FD51, FD52, FD53, FD54, FD55, FD56, FD57, FD58, FD59, FD60, FD61, FD62, FD63, FD64, FD65, FD66, FD67, FD68, FD69, FD70, FD71, FD72, FD73, FD74, FD75, FD76, FD77, FD78, FD79, FD80, FD81, FD82, FD83, FD84, FD85, FD86, FD87, FD88, FD89, FD90, FD91, FD92, FD93, FD94, FD95, FD96, FD97, FD98, FD99, FD100, FD101, FD102, FD103, FD104, FD105, FD106, FD107, FD108, FD109, FD110, FD111, FD112, FD113, FD114, FD115, FD116, FD117, FD118, FD119, FD120, FD121, FD122, FD123, FD124, FD125, FD126, FD127, FD128, FD129, FD130, FD131, FD132, FD133, FD134, FD135, FD136, FD137, FD138, FD139, FD140, FD141, FD142, FD143, FD144, FD145, FD146, FD147, FD148, FD149, FD150, FD151, FD152, FD153, FD154, FD155, FD156, FD157, FD158, FD159, FD160, FD161, FD162, FD163, FD164, FD165, FD166, FD167, FD168, FD169, FD170, FD171, FD172, FD173, FD174, FD175, FD176, FD177, FD178, FD179, FD180, FD181, FD182, FD183, FD184, FD185, FD186, FD187, FD188, FD189, FD190, FD191, FD192, FD193, FD194, FD195, FD196, FD197, FD198, FD199, FD200, FD201, FD202, FD203, FD204, FD205, FD206, FD207, FD208, FD209, FD210, FD211, FD212, FD213, FD214, FD215, FD216, FD217, FD218, FD219, FD220, FD221, FD222, FD223, FD224, FD225, FD226, FD227, FD228, FD229, FD230, FD231, FD232, FD233, FD234, FD235, FD236, FD237, FD238, FD239, FD240, FD241, FD242, FD243, FD244, FD245, FD246, FD247, FD248, FD249, FD250, FD251, FD252, FD253, FD254, FD255, FD256: FIDUCIALUFIDUCIAL; FIDUCIAL-MICRO
FRAME1, FRAME2, FRAME3, FRAME4, FRAME5, FRAME6, FRAME7, FRAME8, FRAME9, FRAME10, FRAME11, FRAME12, FRAME13, FRAME14, FRAME15, FRAME16, FRAME17, FRAME18, FRAME19, FRAME20, FRAME21, FRAME22, FRAME23, FRAME24, FRAME25, FRAME26, FRAME27, FRAME28, FRAME29, FRAME30, FRAME31, FRAME32, FRAME33, FRAME34, FRAME35, FRAME36, FRAME37, FRAME38, FRAME39, FRAME40, FRAME41, FRAME42, FRAME43, FRAME44, FRAME45, FRAME46, FRAME47, FRAME48, FRAME49, FRAME50, FRAME51, FRAME52, FRAME53, FRAME54, FRAME55, FRAME56, FRAME57, FRAME58, FRAME59, FRAME60, FRAME61, FRAME62, FRAME63, FRAME64: FRAME-LETTER; CREATIVE_COMMONS
H1, H2, H3, H4, H5, H6, H7, H8, H9, H10, H11, H12, H13, H14, H15, H16, H17, H18, H19, H20, H21, H22, H23, H24, H25, H26, H27, H28, H29, H30, H31, H32, H33, H34, H35, H36, H37, H38, H39, H40, H41, H42, H43, H44, H45, H46, H47, H48, H49, H50, H51, H52, H53, H54, H55, H56, H57, H58, H59, H60, H61, H62, H63, H64: STAND-OFF
I2C, I2C1, I2C2, I2C3, I2C4, I2C5, I2C6, I2C7, I2C8, I2C9, I2C10, I2C11, I2C12, I2C13, I2C14, I2C15, I2C16, I2C17, I2C18, I2C19, I2C20, I2C21, I2C22, I2C23, I2C24, I2C25, I2C26, I2C27, I2C28, I2C29, I2C30, I2C31, I2C32, I2C33, I2C34, I2C35, I2C36, I2C37, I2C38, I2C39, I2C40, I2C41, I2C42, I2C43, I2C44, I2C45, I2C46, I2C47, I2C48, I2C49, I2C50, I2C51, I2C52, I2C53, I2C54, I2C55, I2C56, I2C57, I2C58, I2C59, I2C60, I2C61, I2C62, I2C63: JUMPER-SMT_3_2-NC_TRACE_SILK; SMT-JUMPER_3_2-NC_TRACE_SILK
J1, J3, J5, J6, J8, J9, J11, J12, J14, J15, J17, J18, J20, J21, J23, J24, J26, J27, J29, J30, J32, J33, J35, J36, J38, J39, J41, J42, J44, J45, J47, J48, J50, J51, J53, J54, J56, J57, J59, J60, J62, J63, J65, J66, J68, J69, J71, J72, J74, J75, J77, J78, J80, J81, J83, J84, J86, J87, J89, J90, J92, J93, J95, J96, J98, J99, J101, J102, J104, J105, J107, J108, J110, J111, J113, J114, J116, J117, J119, J120, J122, J123, J125, J126, J128, J129, J131, J132, J134, J135, J137, J138, J140, J141, J143, J144, J146, J147, J149, J150, J152, J153, J155, J156, J158, J159, J161, J162, J164, J165, J167, J168, J170, J171, J173, J174, J176, J177, J179, J180, J182, J183, J185, J186, J188, J189, J191, J192: 1X01_1MM_NO_SILK
J2, J4, J7, J10, J13, J16, J19, J22, J25, J28, J31, J34, J37, J40, J43, J46, J49, J52, J55, J58, J61, J64, J67, J70, J73, J76, J79, J82, J85, J88, J91, J94, J97, J100, J103, J106, J109, J112, J115, J118, J121, J124, J127, J130, J133, J136, J139, J142, J145, J148, J151, J154, J157, J160, J163, J166, J169, J172, J175, J178, J181, J184, J187, J190: QWIIC_RIGHT_ANGLE; JST04_1MM_RA
LOGO1, LOGO4, LOGO7, LOGO10, LOGO13, LOGO16, LOGO19, LOGO22, LOGO25, LOGO28, LOGO31, LOGO34, LOGO37, LOGO40, LOGO43, LOGO46, LOGO49, LOGO52, LOGO55, LOGO58, LOGO61, LOGO64, LOGO67, LOGO70, LOGO73, LOGO76, LOGO79, LOGO82, LOGO85, LOGO88, LOGO91, LOGO94, LOGO97, LOGO100, LOGO103, LOGO106, LOGO109, LOGO112, LOGO115, LOGO118, LOGO121, LOGO124, LOGO127, LOGO130, LOGO133, LOGO136, LOGO139, LOGO142, LOGO145, LOGO148, LOGO151, LOGO154, LOGO157, LOGO160, LOGO163, LOGO166, LOGO169, LOGO172, LOGO175, LOGO178, LOGO181, LOGO184, LOGO187, LOGO190: OSHW-LOGOS; OSHW-LOGO-S
LOGO2, LOGO5, LOGO8, LOGO11, LOGO14, LOGO17, LOGO20, LOGO23, LOGO26, LOGO29, LOGO32, LOGO35, LOGO38, LOGO41, LOGO44, LOGO47, LOGO50, LOGO53, LOGO56, LOGO59, LOGO62, LOGO65, LOGO68, LOGO71, LOGO74, LOGO77, LOGO80, LOGO83, LOGO86, LOGO89, LOGO92, LOGO95, LOGO98, LOGO101, LOGO104, LOGO107, LOGO110, LOGO113, LOGO116, LOGO119, LOGO122, LOGO125, LOGO128, LOGO131, LOGO134, LOGO137, LOGO140, LOGO143, LOGO146, LOGO149, LOGO152, LOGO155, LOGO158, LOGO161, LOGO164, LOGO167, LOGO170, LOGO173, LOGO176, LOGO179, LOGO182, LOGO185, LOGO188, LOGO191: QWIIC_LOGO_3MM; QWIIC_3MM
LOGO3, LOGO6, LOGO9, LOGO12, LOGO15, LOGO18, LOGO21, LOGO24, LOGO27, LOGO30, LOGO33, LOGO36, LOGO39, LOGO42, LOGO45, LOGO48, LOGO51, LOGO54, LOGO57, LOGO60, LOGO63, LOGO66, LOGO69, LOGO72, LOGO75, LOGO78, LOGO81, LOGO84, LOGO87, LOGO90, LOGO93, LOGO96, LOGO99, LOGO102, LOGO105, LOGO108, LOGO111, LOGO114, LOGO117, LOGO120, LOGO123, LOGO126, LOGO129, LOGO132, LOGO135, LOGO138, LOGO141, LOGO144, LOGO147, LOGO150, LOGO153, LOGO156, LOGO159, LOGO162, LOGO165, LOGO168, LOGO171, LOGO174, LOGO177, LOGO180, LOGO183, LOGO186, LOGO189, LOGO192: SFE_LOGO_NAME_FLAMEBLANK; BLANK
PWR, PWR1, PWR2, PWR3, PWR4, PWR5, PWR6, PWR7, PWR8, PWR9, PWR10, PWR11, PWR12, PWR13, PWR14, PWR15, PWR16, PWR17, PWR18, PWR19, PWR20, PWR21, PWR22, PWR23, PWR24, PWR25, PWR26, PWR27, PWR28, PWR29, PWR30, PWR31, PWR32, PWR33, PWR34, PWR35, PWR36, PWR37, PWR38, PWR39, PWR40, PWR41, PWR42, PWR43, PWR44, PWR45, PWR46, PWR47, PWR48, PWR49, PWR50, PWR51, PWR52, PWR53, PWR54, PWR55, PWR56, PWR57, PWR58, PWR59, PWR60, PWR61, PWR62, PWR63: JUMPER-SMT_2_NC_TRACE_SILK; SMT-JUMPER_2_NC_TRACE_SILK
R1, R2, R5, R6, R7, R10, R11, R12, R15, R16, R17, R20, R21, R22, R25, R26, R27, R30, R31, R32, R35, R36, R37, R40, R41, R42, R45, R46, R47, R50, R51, R52, R55, R56, R57, R60, R61, R62, R65, R66, R67, R70, R71, R72, R75, R76, R77, R80, R81, R82, R85, R86, R87, R90, R91, R92, R95, R96, R97, R100, R101, R102, R105, R106, R107, R110, R111, R112, R115, R116, R117, R120, R121, R122, R125, R126, R127, R130, R131, R132, R135, R136, R137, R140, R141, R142, R145, R146, R147, R150, R151, R152, R155, R156, R157, R160, R161, R162, R165, R166, R167, R170, R171, R172, R175, R176, R177, R180, R181, R182, R185, R186, R187, R190, R191, R192, R195, R196, R197, R200, R201, R202, R205, R206, R207, R210, R211, R212, R215, R216, R217, R220, R221, R222, R225, R226, R227, R230, R231, R232, R235, R236, R237, R240, R241, R242, R245, R246, R247, R250, R251, R252, R255, R256, R257, R260, R261, R262, R265, R266, R267, R270, R271, R272, R275, R276, R277, R280, R281, R282, R285, R286, R287, R290, R291, R292, R295, R296, R297, R300, R301, R302, R305, R306, R307, R310, R311, R312, R315, R316, R317, R320: 2.2k; 0402-TIGHT
R3, R4, R8, R9, R13, R14, R18, R19, R23, R24, R28, R29, R33, R34, R38, R39, R43, R44, R48, R49, R53, R54, R58, R59, R63, R64, R68, R69, R73, R74, R78, R79, R83, R84, R88, R89, R93, R94, R98, R99, R103, R104, R108, R109, R113, R114, R118, R119, R123, R124, R128, R129, R133, R134, R138, R139, R143, R144, R148, R149, R153, R154, R158, R159, R163, R164, R168, R169, R173, R174, R178, R179, R183, R184, R188, R189, R193, R194, R198, R199, R203, R204, R208, R209, R213, R214, R218, R219, R223, R224, R228, R229, R233, R234, R238, R239, R243, R244, R248, R249, R253, R254, R258, R259, R263, R264, R268, R269, R273, R274, R278, R279, R283, R284, R288, R289, R293, R294, R298, R299, R303, R304, R308, R309, R313, R314, R318, R319: 10k; 0402-TIGHT
TP1, TP2, TP3, TP4, TP5, TP6, TP7, TP8, TP9, TP10, TP11, TP12, TP13, TP14, TP15, TP16, TP17, TP18, TP19, TP20, TP21, TP22, TP23, TP24, TP25, TP26, TP27, TP28, TP29, TP30, TP31, TP32, TP33, TP34, TP35, TP36, TP37, TP38, TP39, TP40, TP41, TP42, TP43, TP44, TP45, TP46, TP47, TP48, TP49, TP50, TP51, TP52, TP53, TP54, TP55, TP56, TP57, TP58, TP59, TP60, TP61, TP62, TP63, TP64, TP65, TP66, TP67, TP68, TP69, TP70, TP71, TP72, TP73, TP74, TP75, TP76, TP77, TP78, TP79, TP80, TP81, TP82, TP83, TP84, TP85, TP86, TP87, TP88, TP89, TP90, TP91, TP92, TP93, TP94, TP95, TP96, TP97, TP98, TP99, TP100, TP101, TP102, TP103, TP104, TP105, TP106, TP107, TP108, TP109, TP110, TP111, TP112, TP113, TP114, TP115, TP116, TP117, TP118, TP119, TP120, TP121, TP122, TP123, TP124, TP125, TP126, TP127, TP128, TP129, TP130, TP131, TP132, TP133, TP134, TP135, TP136, TP137, TP138, TP139, TP140, TP141, TP142, TP143, TP144, TP145, TP146, TP147, TP148, TP149, TP150, TP151, TP152, TP153, TP154, TP155, TP156, TP157, TP158, TP159, TP160, TP161, TP162, TP163, TP164, TP165, TP166, TP167, TP168, TP169, TP170, TP171, TP172, TP173, TP174, TP175, TP176, TP177, TP178, TP179, TP180, TP181, TP182, TP183, TP184, TP185, TP186, TP187, TP188, TP189, TP190, TP191, TP192, TP193, TP194, TP195, TP196, TP197, TP198, TP199, TP200, TP201, TP202, TP203, TP204, TP205, TP206, TP207, TP208, TP209, TP210, TP211, TP212, TP213, TP214, TP215, TP216, TP217, TP218, TP219, TP220, TP221, TP222, TP223, TP224, TP225, TP226, TP227, TP228, TP229, TP230, TP231, TP232, TP233, TP234, TP235, TP236, TP237, TP238, TP239, TP240, TP241, TP242, TP243, TP244, TP245, TP246, TP247, TP248, TP249, TP250, TP251, TP252, TP253, TP254, TP255, TP256: TEST-POINT3; PAD.03X.03
U1, U2, U3, U4, U5, U6, U7, U8, U9, U10, U11, U12, U13, U14, U15, U16, U17, U18, U19, U20, U21, U22, U23, U24, U25, U26, U27, U28, U29, U30, U31, U32, U33, U34, U35, U36, U37, U38, U39, U40, U41, U42, U43, U44, U45, U46, U47, U48, U49, U50, U51, U52, U53, U54, U55, U56, U57, U58, U59, U60, U61, U62, U63, U64: LPS28DFW
U$1, U$3, U$15, U$19, U$28, U$30, U$39, U$41, U$50, U$52, U$61, U$63, U$72, U$74, U$83, U$85, U$94, U$96, U$105, U$107, U$116, U$118, U$127, U$129, U$138, U$140, U$149, U$151, U$160, U$162, U$171, U$173, U$182, U$184, U$193, U$195, U$204, U$206, U$215, U$217, U$226, U$228, U$237, U$239, U$248, U$250, U$259, U$261, U$270, U$272, U$281, U$283, U$292, U$294, U$303, U$305, U$314, U$316, U$325, U$327, U$336, U$338, U$347, U$349, U$358, U$360, U$369, U$371, U$380, U$382, U$391, U$393, U$402, U$404, U$413, U$415, U$424, U$426, U$435, U$437, U$446, U$448, U$457, U$459, U$468, U$470, U$479, U$481, U$490, U$492, U$501, U$503, U$512, U$514, U$523, U$525, U$534, U$536, U$545, U$547, U$556, U$558, U$567, U$569, U$578, U$580, U$589, U$591, U$600, U$602, U$611, U$613, U$622, U$624, U$633, U$635, U$644, U$646, U$655, U$657, U$666, U$668, U$677, U$679, U$688, U$690, U$699, U$701: #INT#0
U$2, U$4, U$18, U$20, U$29, U$31, U$40, U$42, U$51, U$53, U$62, U$64, U$73, U$75, U$84, U$86, U$95, U$97, U$106, U$108, U$117, U$119, U$128, U$130, U$139, U$141, U$150, U$152, U$161, U$163, U$172, U$174, U$183, U$185, U$194, U$196, U$205, U$207, U$216, U$218, U$227, U$229, U$238, U$240, U$249, U$251, U$260, U$262, U$271, U$273, U$282, U$284, U$293, U$295, U$304, U$306, U$315, U$317, U$326, U$328, U$337, U$339, U$348, U$350, U$359, U$361, U$370, U$372, U$381, U$383, U$392, U$394, U$403, U$405, U$414, U$416, U$425, U$427, U$436, U$438, U$447, U$449, U$458, U$460, U$469, U$471, U$480, U$482, U$491, U$493, U$502, U$504, U$513, U$515, U$524, U$526, U$535, U$537, U$546, U$548, U$557, U$559, U$568, U$570, U$579, U$581, U$590, U$592, U$601, U$603, U$612, U$614, U$623, U$625, U$634, U$636, U$645, U$647, U$656, U$658, U$667, U$669, U$678, U$680, U$689, U$691, U$700, U$702: #GND#0
U$5, U$21, U$32, U$43, U$54, U$65, U$76, U$87, U$98, U$109, U$120, U$131, U$142, U$153, U$164, U$175, U$186, U$197, U$208, U$219, U$230, U$241, U$252, U$263, U$274, U$285, U$296, U$307, U$318, U$329, U$340, U$351, U$362, U$373, U$384, U$395, U$406, U$417, U$428, U$439, U$450, U$461, U$472, U$483, U$494, U$505, U$516, U$527, U$538, U$549, U$560, U$571, U$582, U$593, U$604, U$615, U$626, U$637, U$648, U$659, U$670, U$681, U$692, U$703: LPS28DFW0
U$6, U$22, U$33, U$44, U$55, U$66, U$77, U$88, U$99, U$110, U$121, U$132, U$143, U$154, U$165, U$176, U$187, U$198, U$209, U$220, U$231, U$242, U$253, U$264, U$275, U$286, U$297, U$308, U$319, U$330, U$341, U$352, U$363, U$374, U$385, U$396, U$407, U$418, U$429, U$440, U$451, U$462, U$473, U$484, U$495, U$506, U$517, U$528, U$539, U$550, U$561, U$572, U$583, U$594, U$605, U$616, U$627, U$638, U$649, U$660, U$671, U$682, U$693, U$704: SFE_LOGO_FLAME_.1
U$7, U$9, U$23, U$34, U$45, U$56, U$67, U$78, U$89, U$100, U$111, U$122, U$133, U$144, U$155, U$166, U$177, U$188, U$199, U$210, U$221, U$232, U$243, U$254, U$265, U$276, U$287, U$298, U$309, U$320, U$331, U$342, U$353, U$364, U$375, U$386, U$397, U$408, U$419, U$430, U$441, U$452, U$463, U$474, U$485, U$496, U$507, U$518, U$529, U$540, U$551, U$562, U$573, U$584, U$595, U$606, U$617, U$628, U$639, U$650, U$661, U$672, U$683, U$694: #I2C#0
U$8, U$10, U$24, U$35, U$46, U$57, U$68, U$79, U$90, U$101, U$112, U$123, U$134, U$145, U$156, U$167, U$178, U$189, U$200, U$211, U$222, U$233, U$244, U$255, U$266, U$277, U$288, U$299, U$310, U$321, U$332, U$343, U$354, U$365, U$376, U$387, U$398, U$409, U$420, U$431, U$442, U$453, U$464, U$475, U$486, U$497, U$508, U$519, U$530, U$541, U$552, U$563, U$574, U$585, U$596, U$607, U$618, U$629, U$640, U$651, U$662, U$673, U$684, U$695: #ADR#0
U$11, U$13, U$25, U$36, U$47, U$58, U$69, U$80, U$91, U$102, U$113, U$124, U$135, U$146, U$157, U$168, U$179, U$190, U$201, U$212, U$223, U$234, U$245, U$256, U$267, U$278, U$289, U$300, U$311, U$322, U$333, U$344, U$355, U$366, U$377, U$388, U$399, U$410, U$421, U$432, U$443, U$454, U$465, U$476, U$487, U$498, U$509, U$520, U$531, U$542, U$553, U$564, U$575, U$586, U$597, U$608, U$619, U$630, U$641, U$652, U$663, U$674, U$685, U$696: #PWR#0
U$12, U$16, U$26, U$37, U$48, U$59, U$70, U$81, U$92, U$103, U$114, U$125, U$136, U$147, U$158, U$169, U$180, U$191, U$202, U$213, U$224, U$235, U$246, U$257, U$268, U$279, U$290, U$301, U$312, U$323, U$334, U$345, U$356, U$367, U$378, U$389, U$400, U$411, U$422, U$433, U$444, U$455, U$466, U$477, U$488, U$499, U$510, U$521, U$532, U$543, U$554, U$565, U$576, U$587, U$598, U$609, U$620, U$631, U$642, U$653, U$664, U$675, U$686, U$697: #0X5D#0
U$14, U$17, U$27, U$38, U$49, U$60, U$71, U$82, U$93, U$104, U$115, U$126, U$137, U$148, U$159, U$170, U$181, U$192, U$203, U$214, U$225, U$236, U$247, U$258, U$269, U$280, U$291, U$302, U$313, U$324, U$335, U$346, U$357, U$368, U$379, U$390, U$401, U$412, U$423, U$434, U$445, U$456, U$467, U$478, U$489, U$500, U$511, U$522, U$533, U$544, U$555, U$566, U$577, U$588, U$599, U$610, U$621, U$632, U$643, U$654, U$665, U$676, U$687, U$698: #0X5C#0

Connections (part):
3.3V: C1.1, I2C.2, J2.2, PWR.2, R3.2, TP2.1, U1.6
3.3V1: C2.1, I2C1.2, J4.2, PWR1.2, R8.2, TP6.1, U2.6
3.3V2: C3.1, I2C2.2, J7.2, PWR2.2, R13.2, TP10.1, U3.6
3.3V3: C4.1, I2C3.2, J10.2, PWR3.2, R18.2, TP14.1, U4.6
3.3V4: C5.1, I2C4.2, J13.2, PWR4.2, R23.2, TP18.1, U5.6
3.3V5: C6.1, I2C5.2, J16.2, PWR5.2, R28.2, TP22.1, U6.6
3.3V6: C7.1, I2C6.2, J19.2, PWR6.2, R33.2, TP26.1, U7.6
3.3V7: C8.1, I2C7.2, J22.2, PWR7.2, R38.2, TP30.1, U8.6
3.3V8: C9.1, I2C8.2, J25.2, PWR8.2, R43.2, TP34.1, U9.6
3.3V9: C10.1, I2C9.2, J28.2, PWR9.2, R48.2, TP38.1, U10.6
3.3V10: C11.1, I2C10.2, J31.2, PWR10.2, R53.2, TP42.1, U11.6
3.3V11: C12.1, I2C11.2, J34.2, PWR11.2, R58.2, TP46.1, U12.6
3.3V12: C13.1, I2C12.2, J37.2, PWR12.2, R63.2, TP50.1, U13.6
3.3V13: C14.1, I2C13.2, J40.2, PWR13.2, R68.2, TP54.1, U14.6
3.3V14: C15.1, I2C14.2, J43.2, PWR14.2, R73.2, TP58.1, U15.6
3.3V15: C16.1, I2C15.2, J46.2, PWR15.2, R78.2, TP62.1, U16.6
3.3V16: C17.1, I2C16.2, J49.2, PWR16.2, R83.2, TP66.1, U17.6
3.3V17: C18.1, I2C17.2, J52.2, PWR17.2, R88.2, TP70.1, U18.6
3.3V18: C19.1, I2C18.2, J55.2, PWR18.2, R93.2, TP74.1, U19.6
3.3V19: C20.1, I2C19.2, J58.2, PWR19.2, R98.2, TP78.1, U20.6
3.3V20: C21.1, I2C20.2, J61.2, PWR20.2, R103.2, TP82.1, U21.6
3.3V21: C22.1, I2C21.2, J64.2, PWR21.2, R108.2, TP86.1, U22.6
3.3V22: C23.1, I2C22.2, J67.2, PWR22.2, R113.2, TP90.1, U23.6
3.3V23: C24.1, I2C23.2, J70.2, PWR23.2, R118.2, TP94.1, U24.6
3.3V24: C25.1, I2C24.2, J73.2, PWR24.2, R123.2, TP98.1, U25.6
3.3V25: C26.1, I2C25.2, J76.2, PWR25.2, R128.2, TP102.1, U26.6
3.3V26: C27.1, I2C26.2, J79.2, PWR26.2, R133.2, TP106.1, U27.6
3.3V27: C28.1, I2C27.2, J82.2, PWR27.2, R138.2, TP110.1, U28.6
3.3V28: C29.1, I2C28.2, J85.2, PWR28.2, R143.2, TP114.1, U29.6
3.3V29: C30.1, I2C29.2, J88.2, PWR29.2, R148.2, TP118.1, U30.6
3.3V30: C31.1, I2C30.2, J91.2, PWR30.2, R153.2, TP122.1, U31.6
3.3V31: C32.1, I2C31.2, J94.2, PWR31.2, R158.2, TP126.1, U32.6
3.3V32: C33.1, I2C32.2, J97.2, PWR32.2, R163.2, TP130.1, U33.6
3.3V33: C34.1, I2C33.2, J100.2, PWR33.2, R168.2, TP134.1, U34.6
3.3V34: C35.1, I2C34.2, J103.2, PWR34.2, R173.2, TP138.1, U35.6
3.3V35: C36.1, I2C35.2, J106.2, PWR35.2, R178.2, TP142.1, U36.6
3.3V36: C37.1, I2C36.2, J109.2, PWR36.2, R183.2, TP146.1, U37.6
3.3V37: C38.1, I2C37.2, J112.2, PWR37.2, R188.2, TP150.1, U38.6
3.3V38: C39.1, I2C38.2, J115.2, PWR38.2, R193.2, TP154.1, U39.6
3.3V39: C40.1, I2C39.2, J118.2, PWR39.2, R198.2, TP158.1, U40.6
3.3V40: C41.1, I2C40.2, J121.2, PWR40.2, R203.2, TP162.1, U41.6
3.3V41: C42.1, I2C41.2, J124.2, PWR41.2, R208.2, TP166.1, U42.6
3.3V42: C43.1, I2C42.2, J127.2, PWR42.2, R213.2, TP170.1, U43.6
3.3V43: C44.1, I2C43.2, J130.2, PWR43.2, R218.2, TP174.1, U44.6
3.3V44: C45.1, I2C44.2, J133.2, PWR44.2, R223.2, TP178.1, U45.6
3.3V45: C46.1, I2C45.2, J136.2, PWR45.2, R228.2, TP182.1, U46.6
3.3V46: C47.1, I2C46.2, J139.2, PWR46.2, R233.2, TP186.1, U47.6
3.3V47: C48.1, I2C47.2, J142.2, PWR47.2, R238.2, TP190.1, U48.6
3.3V48: C49.1, I2C48.2, J145.2, PWR48.2, R243.2, TP194.1, U49.6
3.3V49: C50.1, I2C49.2, J148.2, PWR49.2, R248.2, TP198.1, U50.6
3.3V50: C51.1, I2C50.2, J151.2, PWR50.2, R253.2, TP202.1, U51.6
3.3V51: C52.1, I2C51.2, J154.2, PWR51.2, R258.2, TP206.1, U52.6
3.3V52: C53.1, I2C52.2, J157.2, PWR52.2, R263.2, TP210.1, U53.6
3.3V53: C54.1, I2C53.2, J160.2, PWR53.2, R268.2, TP214.1, U54.6
3.3V54: C55.1, I2C54.2, J163.2, PWR54.2, R273.2, TP218.1, U55.6
3.3V55: C56.1, I2C55.2, J166.2, PWR55.2, R278.2, TP222.1, U56.6
3.3V56: C57.1, I2C56.2, J169.2, PWR56.2, R283.2, TP226.1, U57.6
3.3V57: C58.1, I2C57.2, J172.2, PWR57.2, R288.2, TP230.1, U58.6
3.3V58: C59.1, I2C58.2, J175.2, PWR58.2, R293.2, TP234.1, U59.6
3.3V59: C60.1, I2C59.2, J178.2, PWR59.2, R298.2, TP238.1, U60.6
3.3V60: C61.1, I2C60.2, J181.2, PWR60.2, R303.2, TP242.1, U61.6
3.3V61: C62.1, I2C61.2, J184.2, PWR61.2, R308.2, TP246.1, U62.6
3.3V62: C63.1, I2C62.2, J187.2, PWR62.2, R313.2, TP250.1, U63.6
3.3V63: C64.1, I2C63.2, J190.2, PWR63.2, R318.2, TP254.1, U64.6
ADR: ADR.2, U1.2
ADR1: ADR1.2, U2.2
ADR2: ADR2.2, U3.2
ADR3: ADR3.2, U4.2
ADR4: ADR4.2, U5.2
ADR5: ADR5.2, U6.2
ADR6: ADR6.2, U7.2
ADR7: ADR7.2, U8.2
ADR8: ADR8.2, U9.2
ADR9: ADR9.2, U10.2
ADR10: ADR10.2, U11.2
ADR11: ADR11.2, U12.2
ADR12: ADR12.2, U13.2
ADR13: ADR13.2, U14.2
ADR14: ADR14.2, U15.2
ADR15: ADR15.2, U16.2
ADR16: ADR16.2, U17.2
ADR17: ADR17.2, U18.2
ADR18: ADR18.2, U19.2
ADR19: ADR19.2, U20.2
ADR20: ADR20.2, U21.2
ADR21: ADR21.2, U22.2
ADR22: ADR22.2, U23.2
ADR23: ADR23.2, U24.2
ADR24: ADR24.2, U25.2
ADR25: ADR25.2, U26.2
ADR26: ADR26.2, U27.2
ADR27: ADR27.2, U28.2
ADR28: ADR28.2, U29.2
ADR29: ADR29.2, U30.2
ADR30: ADR30.2, U31.2
ADR31: ADR31.2, U32.2
ADR32: ADR32.2, U33.2
ADR33: ADR33.2, U34.2
ADR34: ADR34.2, U35.2
ADR35: ADR35.2, U36.2
ADR36: ADR36.2, U37.2
ADR37: ADR37.2, U38.2
ADR38: ADR38.2, U39.2
ADR39: ADR39.2, U40.2
ADR40: ADR40.2, U41.2
ADR41: ADR41.2, U42.2
ADR42: ADR42.2, U43.2
ADR43: ADR43.2, U44.2
ADR44: ADR44.2, U45.2
ADR45: ADR45.2, U46.2
ADR46: ADR46.2, U47.2
ADR47: ADR47.2, U48.2
ADR48: ADR48.2, U49.2
ADR49: ADR49.2, U50.2
ADR50: ADR50.2, U51.2
ADR51: ADR51.2, U52.2
ADR52: ADR52.2, U53.2
ADR53: ADR53.2, U54.2
ADR54: ADR54.2, U55.2
ADR55: ADR55.2, U56.2
ADR56: ADR56.2, U57.2
ADR57: ADR57.2, U58.2
ADR58: ADR58.2, U59.2
ADR59: ADR59.2, U60.2
ADR60: ADR60.2, U61.2
ADR61: ADR61.2, U62.2
ADR62: ADR62.2, U63.2
ADR63: ADR63.2, U64.2
GND: C1.2, J1.1, J2.1, R4.1, R5.1, TP1.1, U1.5, U1.7
GND1: C2.2, J4.1, J6.1, R9.1, R10.1, TP5.1, U2.5, U2.7
GND2: C3.2, J7.1, J9.1, R14.1, R15.1, TP9.1, U3.5, U3.7
GND3: C4.2, J10.1, J12.1, R19.1, R20.1, TP13.1, U4.5, U4.7
GND4: C5.2, J13.1, J15.1, R24.1, R25.1, TP17.1, U5.5, U5.7
GND5: C6.2, J16.1, J18.1, R29.1, R30.1, TP21.1, U6.5, U6.7
GND6: C7.2, J19.1, J21.1, R34.1, R35.1, TP25.1, U7.5, U7.7
GND7: C8.2, J22.1, J24.1, R39.1, R40.1, TP29.1, U8.5, U8.7
GND8: C9.2, J25.1, J27.1, R44.1, R45.1, TP33.1, U9.5, U9.7
GND9: C10.2, J28.1, J30.1, R49.1, R50.1, TP37.1, U10.5, U10.7
GND10: C11.2, J31.1, J33.1, R54.1, R55.1, TP41.1, U11.5, U11.7
GND11: C12.2, J34.1, J36.1, R59.1, R60.1, TP45.1, U12.5, U12.7
GND12: C13.2, J37.1, J39.1, R64.1, R65.1, TP49.1, U13.5, U13.7
GND13: C14.2, J40.1, J42.1, R69.1, R70.1, TP53.1, U14.5, U14.7
GND14: C15.2, J43.1, J45.1, R74.1, R75.1, TP57.1, U15.5, U15.7
GND15: C16.2, J46.1, J48.1, R79.1, R80.1, TP61.1, U16.5, U16.7
GND16: C17.2, J49.1, J51.1, R84.1, R85.1, TP65.1, U17.5, U17.7
GND17: C18.2, J52.1, J54.1, R89.1, R90.1, TP69.1, U18.5, U18.7
GND18: C19.2, J55.1, J57.1, R94.1, R95.1, TP73.1, U19.5, U19.7
GND19: C20.2, J58.1, J60.1, R99.1, R100.1, TP77.1, U20.5, U20.7
GND20: C21.2, J61.1, J63.1, R104.1, R105.1, TP81.1, U21.5, U21.7
GND21: C22.2, J64.1, J66.1, R109.1, R110.1, TP85.1, U22.5, U22.7
GND22: C23.2, J67.1, J69.1, R114.1, R115.1, TP89.1, U23.5, U23.7
GND23: C24.2, J70.1, J72.1, R119.1, R120.1, TP93.1, U24.5, U24.7
GND24: C25.2, J73.1, J75.1, R124.1, R125.1, TP97.1, U25.5, U25.7
GND25: C26.2, J76.1, J78.1, R129.1, R130.1, TP101.1, U26.5, U26.7
GND26: C27.2, J79.1, J81.1, R134.1, R135.1, TP105.1, U27.5, U27.7
GND27: C28.2, J82.1, J84.1, R139.1, R140.1, TP109.1, U28.5, U28.7
GND28: C29.2, J85.1, J87.1, R144.1, R145.1, TP113.1, U29.5, U29.7
GND29: C30.2, J88.1, J90.1, R149.1, R150.1, TP117.1, U30.5, U30.7
GND30: C31.2, J91.1, J93.1, R154.1, R155.1, TP121.1, U31.5, U31.7
GND31: C32.2, J94.1, J96.1, R159.1, R160.1, TP125.1, U32.5, U32.7
GND32: C33.2, J97.1, J99.1, R164.1, R165.1, TP129.1, U33.5, U33.7
GND33: C34.2, J100.1, J102.1, R169.1, R170.1, TP133.1, U34.5, U34.7
GND34: C35.2, J103.1, J105.1, R174.1, R175.1, TP137.1, U35.5, U35.7
GND35: C36.2, J106.1, J108.1, R179.1, R180.1, TP141.1, U36.5, U36.7
GND36: C37.2, J109.1, J111.1, R184.1, R185.1, TP145.1, U37.5, U37.7
GND37: C38.2, J112.1, J114.1, R189.1, R190.1, TP149.1, U38.5, U38.7
GND38: C39.2, J115.1, J117.1, R194.1, R195.1, TP153.1, U39.5, U39.7
GND39: C40.2, J118.1, J120.1, R199.1, R200.1, TP157.1, U40.5, U40.7
GND40: C41.2, J121.1, J123.1, R204.1, R205.1, TP161.1, U41.5, U41.7
GND41: C42.2, J124.1, J126.1, R209.1, R210.1, TP165.1, U42.5, U42.7
GND42: C43.2, J127.1, J129.1, R214.1, R215.1, TP169.1, U43.5, U43.7
GND43: C44.2, J130.1, J132.1, R219.1, R220.1, TP173.1, U44.5, U44.7
GND44: C45.2, J133.1, J135.1, R224.1, R225.1, TP177.1, U45.5, U45.7
GND45: C46.2, J136.1, J138.1, R229.1, R230.1, TP181.1, U46.5, U46.7
GND46: C47.2, J139.1, J141.1, R234.1, R235.1, TP185.1, U47.5, U47.7
GND47: C48.2, J142.1, J144.1, R239.1, R240.1, TP189.1, U48.5, U48.7
GND48: C49.2, J145.1, J147.1, R244.1, R245.1, TP193.1, U49.5, U49.7
GND49: C50.2, J148.1, J150.1, R249.1, R250.1, TP197.1, U50.5, U50.7
GND50: C51.2, J151.1, J153.1, R254.1, R255.1, TP201.1, U51.5, U51.7
GND51: C52.2, J154.1, J156.1, R259.1, R260.1, TP205.1, U52.5, U52.7
GND52: C53.2, J157.1, J159.1, R264.1, R265.1, TP209.1, U53.5, U53.7
GND53: C54.2, J160.1, J162.1, R269.1, R270.1, TP213.1, U54.5, U54.7
GND54: C55.2, J163.1, J165.1, R274.1, R275.1, TP217.1, U55.5, U55.7
GND55: C56.2, J166.1, J168.1, R279.1, R280.1, TP221.1, U56.5, U56.7
GND56: C57.2, J169.1, J171.1, R284.1, R285.1, TP225.1, U57.5, U57.7
GND57: C58.2, J172.1, J174.1, R289.1, R290.1, TP229.1, U58.5, U58.7
GND58: C59.2, J175.1, J177.1, R294.1, R295.1, TP233.1, U59.5, U59.7
GND59: C60.2, J178.1, J180.1, R299.1, R300.1, TP237.1, U60.5, U60.7
GND60: C61.2, J181.1, J183.1, R304.1, R305.1, TP241.1, U61.5, U61.7
GND61: C62.2, J184.1, J186.1, R309.1, R310.1, TP245.1, U62.5, U62.7
GND62: C63.2, J187.1, J189.1, R314.1, R315.1, TP249.1, U63.5, U63.7
GND63: C64.2, J190.1, J192.1, R319.1, R320.1, TP253.1, U64.5, U64.7
INT: J3.1, U1.4
INT1: J5.1, U2.4
INT2: J8.1, U3.4
INT3: J11.1, U4.4
INT4: J14.1, U5.4
INT5: J17.1, U6.4
INT6: J20.1, U7.4
INT7: J23.1, U8.4
INT8: J26.1, U9.4
INT9: J29.1, U10.4
INT10: J32.1, U11.4
INT11: J35.1, U12.4
INT12: J38.1, U13.4
INT13: J41.1, U14.4
INT14: J44.1, U15.4
INT15: J47.1, U16.4
INT16: J50.1, U17.4
INT17: J53.1, U18.4
INT18: J56.1, U19.4
INT19: J59.1, U20.4
INT20: J62.1, U21.4
INT21: J65.1, U22.4
INT22: J68.1, U23.4
INT23: J71.1, U24.4
INT24: J74.1, U25.4
INT25: J77.1, U26.4
INT26: J80.1, U27.4
INT27: J83.1, U28.4
INT28: J86.1, U29.4
INT29: J89.1, U30.4
INT30: J92.1, U31.4
INT31: J95.1, U32.4
INT32: J98.1, U33.4
INT33: J101.1, U34.4
INT34: J104.1, U35.4
INT35: J107.1, U36.4
INT36: J110.1, U37.4
INT37: J113.1, U38.4
INT38: J116.1, U39.4
INT39: J119.1, U40.4
INT40: J122.1, U41.4
INT41: J125.1, U42.4
INT42: J128.1, U43.4
INT43: J131.1, U44.4
INT44: J134.1, U45.4
INT45: J137.1, U46.4
INT46: J140.1, U47.4
INT47: J143.1, U48.4
INT48: J146.1, U49.4
INT49: J149.1, U50.4
INT50: J152.1, U51.4
INT51: J155.1, U52.4
INT52: J158.1, U53.4
INT53: J161.1, U54.4
INT54: J164.1, U55.4
INT55: J167.1, U56.4
INT56: J170.1, U57.4
INT57: J173.1, U58.4
INT58: J176.1, U59.4
INT59: J179.1, U60.4
INT60: J182.1, U61.4
INT61: J185.1, U62.4
INT62: J188.1, U63.4
INT63: J191.1, U64.4
unnamed: D1.C, R5.2
unnamed: I2C.3, R1.2
unnamed: I2C.1, R2.1
unnamed: D1.A, PWR.1
unnamed: ADR.3, R4.2
unnamed: ADR.1, R3.1
unnamed: I2C1.3, R6.2
unnamed: I2C1.1, R7.1
unnamed: ADR1.3, R9.2
unnamed: ADR1.1, R8.1
unnamed: D2.C, R10.2
unnamed: D2.A, PWR1.1
unnamed: I2C2.3, R11.2
unnamed: I2C2.1, R12.1
unnamed: ADR2.3, R14.2
unnamed: ADR2.1, R13.1
unnamed: D3.C, R15.2
unnamed: D3.A, PWR2.1
unnamed: I2C3.3, R16.2
unnamed: I2C3.1, R17.1
unnamed: ADR3.3, R19.2
unnamed: ADR3.1, R18.1
unnamed: D4.C, R20.2
unnamed: D4.A, PWR3.1
unnamed: I2C4.3, R21.2
unnamed: I2C4.1, R22.1
unnamed: ADR4.3, R24.2
unnamed: ADR4.1, R23.1
unnamed: D5.C, R25.2
unnamed: D5.A, PWR4.1
unnamed: I2C5.3, R26.2
unnamed: I2C5.1, R27.1
unnamed: ADR5.3, R29.2
unnamed: ADR5.1, R28.1
unnamed: D6.C, R30.2
unnamed: D6.A, PWR5.1
unnamed: I2C6.3, R31.2
unnamed: I2C6.1, R32.1
unnamed: ADR6.3, R34.2
unnamed: ADR6.1, R33.1
unnamed: D7.C, R35.2
unnamed: D7.A, PWR6.1
unnamed: I2C7.3, R36.2
unnamed: I2C7.1, R37.1
unnamed: ADR7.3, R39.2
unnamed: ADR7.1, R38.1
unnamed: D8.C, R40.2
unnamed: D8.A, PWR7.1
unnamed: I2C8.3, R41.2
unnamed: I2C8.1, R42.1
unnamed: ADR8.3, R44.2
unnamed: ADR8.1, R43.1
unnamed: D9.C, R45.2
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

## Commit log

2022-09-19 Create initial schematic and board layout
    [SparkFun_Qwiic_Barometer_LPS28DFW.brd, SparkFun_Qwiic_Barometer_LPS28DFW.sch]
2022-09-19 Add initial Qwiic Micro schematic and board layout
    [SparkFun_Qwiic_Micro_Barometer_LPS28DFW.brd, SparkFun_Qwiic_Micro_Barometer_LPS28DFW.sch]
2022-09-19 Update 1x1 with mirrored LPS28DFW footprint
    [SparkFun_Qwiic_Barometer_LPS28DFW.brd, SparkFun_Qwiic_Barometer_LPS28DFW.sch]
2022-09-19 Update Micro with mirrored LPS28DFW footprint
    [SparkFun_Qwiic_Micro_Barometer_LPS28DFW.brd, SparkFun_Qwiic_Micro_Barometer_LPS28DFW.sch]
2022-09-20 Design review updates
    Add silk to PWR LED on 1x1
    Tweak routing to use more T-junctions and route into side of pads rather than corners
    Move via on I2C jumper silk of Micro
    [SparkFun_Qwiic_Barometer_LPS28DFW.brd, SparkFun_Qwiic_Micro_Barometer_LPS28DFW.brd]
2022-09-20 Move LPS28DFW pin 1 indicator silk
    [SparkFun_Qwiic_Barometer_LPS28DFW.brd, SparkFun_Qwiic_Barometer_LPS28DFW.sch, SparkFun_Qwiic_Micro_Barometer_LPS28DFW.brd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]
2022-09-26 Add PROD_ID to LPS28DFW
    [SparkFun_Qwiic_Barometer_LPS28DFW.brd, SparkFun_Qwiic_Barometer_LPS28DFW.sch, SparkFun_Qwiic_Micro_Barometer_LPS28DFW.brd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]
2022-10-20 Design review updates
    Both:
    Bump version number to v10
    Change LPS28DF section name to "Barometer - LPS28DFW" in schematics
    Remove SPI from ADR jumper in schematics
    Add ordering instructions to boards
    1x1:
    Make SCL and SDA traces not overlap near Qwiic connector
    Move OSHW down between connector and standoff
    Move I@C jumper up to give more GND pour under sensor
    Add SparkFun logo to bottom silk
    Micro:
    Space out test points in schematic
    Add text about 22 AWG wires in schematic
    Move OSHW logo up slightly to not clip at test points
    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
    [SparkFun_Qwiic_Barometer_LPS28DFW.brd, SparkFun_Qwiic_Barometer_LPS28DFW.sch, SparkFun_Qwiic_Micro_Barometer_LPS28DFW.brd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]
2022-10-20 Move OSHW logo in 1x1
    [SparkFun_Qwiic_Barometer_LPS28DFW.brd]
2022-10-20 Create v10 panels
    [SparkFun_Qwiic_Barometer_LPS28DFW-Panel.GBL, SparkFun_Qwiic_Barometer_LPS28DFW-Panel.GBO, SparkFun_Qwiic_Barometer_LPS28DFW-Panel.GBP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]
2023-03-28 Remove library file
    Part is in SFE Eagle library, update part in design
    [SparkFun_Qwiic_Barometer_LPS28DFW.brd, SparkFun_Qwiic_Barometer_LPS28DFW.sch, SparkFun_Qwiic_Micro_Barometer_LPS28DFW.brd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]

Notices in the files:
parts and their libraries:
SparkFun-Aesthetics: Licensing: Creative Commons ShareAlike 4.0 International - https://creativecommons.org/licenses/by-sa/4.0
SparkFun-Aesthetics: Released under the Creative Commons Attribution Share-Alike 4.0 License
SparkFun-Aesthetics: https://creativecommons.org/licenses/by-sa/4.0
